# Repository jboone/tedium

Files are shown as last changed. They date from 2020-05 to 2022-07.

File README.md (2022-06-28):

# tedium

TDM telephony experimentation

## Dependencies

* `oss-cad-suite`: open-source digital design and verification tools, with [nightly binary builds](https://github.com/YosysHQ/oss-cad-suite-build).
* [`poetry`](https://python-poetry.org/): Python dependencies and packaging management tool.
* `g++-riscv64-linux-gnu`
* `rustup toolchain install stable -t riscv32i-unknown-none-elf`

## Installation

Clone this repository, and generally follow these steps:

```bash
$ cd tedium
# Grant access through `udev` to the FTDI JTAG interface on the Tedium board.
$ sudo ln -sf ./99-tedium.rules /etc/udev/rules.d/
$ sudo udevadm control --reload-rules && sudo udevadm trigger
#
$ pip3 install poetry --user
# Might need to log out and in to get ~/.local/bin in PATH.
# Or, `source ~/.profile`.
# Set up virtual environment, download and install dependencies
$ poetry install
# Enter poetry shell
$ poetry shell
# Include OSS CAD Suite tools in PATH
$ export PATH="/home/jboone/src/fpga/oss-cad-suite/bin:$PATH"
# Build and download FPGA bitstream
# LUNA_AVOID_BLOCKRAM required for reliable USB enumeration as of 2022/May/02.
$ LUNA_AVOID_BLOCKRAM=1 applets/tedium-fpga
# After the bitstream is generated, you can inspect the results in the `build` directory.
# Initialize the framer/LIU
$ cargo run --release --bin tedium-tool -- init
# Run the host-side audio and event engine
$ cargo run --release --bin tedium-tool -- monitor
```

NOTE: My Tedium .venv got weird when I had the "OSS CAD Suite" environment already enabled.
Poetry would download dependencies on `poetry install` or `poetry update`, but would then
delete them when running `poetry run` or `poetry shell`.

## Testing

Unit tests may be run like this:

```bash
$ python3 -m unittest tests.hdl.tx_usb_to_fifo
# Or the name of any other HDL test module you want to run/simulate.
```

## USB Debugging

```bash
$ sudo cat /sys/kernel/debug/usb/devices
$ sudo cat /sys/kernel/debug/dynamic_debug/control | grep "snd_usb_audio"
$ sudo echo 'file sound/usb/* +p' >/sys/kernel/debug/dynamic_debug/control
$ sudo sysctl -w kernel.printk=7 # debug-level messages
$ sudo sysctl kernel.printk
```

### Using Wireshark

```bash
$ sudo modprobe usbmon
$ sudo wireshark
# Capture stuff
```

Wireshark filters that might be of use:

```
# Find USB IN on endpoint 1, where the frame of completed inbound URBs is not the typical length.
# This helps find where the async audio input FIFO level is wrapping around.
usb.endpoint_address.number==1 && usb.endpoint_address.direction==IN && usb.urb_type=='C' && frame.len != 1728
# Set the time reference at an interesting record in Wireshark, disable view filtering, and work from there.
# Note that "marked" records appear regardless of whether they match the view filter, which is very handy.
# Now match on USB OUT records that have been submitted (pending transmission)
usb.endpoint_address.number==1 && usb.endpoint_address.direction==OUT && usb.urb_type=='S'
```

However, it seems like Wireshark isn't showing complete URB buffer contents?

## Trouble With Real-Time Kit

```bash
# Is there an `rtkit` user?
$ getent passwd rtkit
# Is there an `rtkit*` user?
$ ps ax | grep -i rtkit
# Check that RTKit is actually changing our process/thread priority:
$ journalctl -e -t rtkit-daemon
# `ulimit` values:
$ ulimit -a
```

## Use

See [the software README](tedium/README.md) for information on how to use `tedium-tool` to interact with the hardware over USB.

## License

This software and gateware in this project is licensed under the [BSD 3-Clause License](LICENSE-BSD-3-Clause).

The hardware is licensed under the [CERN Open Hardware Licence Version 2 - Permissive](LICENSE-CERN-OHL-P-v2).

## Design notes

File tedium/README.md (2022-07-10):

# Hardware Setup

The anticipated use case will be for Tedium to recover the clock on span 0 and distribute it to all spans (including span 0 TX).

* Tedium span 0: T-BERD 950 "Line" (primary system clock source)
* Tedium span 1: Adit 1 span 0 (primary source for Adit 1)
* Tedium span 2: Adit 1 span 1 (secondary source for Adit 1)

The T-BERD should be set up accordingly:

* Main
  * Interface: T1
  * Test Type: VOICE

* Setup
  * Mode: TERMINATE
  * Framing: ESF
  * Line Coding: B8ZS
  * Line Rx In: TERM
  * Tx/Rx Pair: LINE
  * Tx Timing: INTERNAL

Don't use the T-BERD "Equipment" DDS-LL port, as it's pretty certain it doesn't do what I'd expect and need it to do.

The Adit 600 should be set up accordingly:

"""
set a:1 up
set a:1 framing esf
set a:1 linecode b8zs
set a:1 lbo 1
set a:1 fdl t1403
set a:1 loopdetect csu
set a:1 payload loopdown
set a:1 ais disable

set a:1:all type voice
set a:1:all signal ls

# Transmit clocks, primary and secondary
# Use the first span RX as the TX source, then the second span RX.
set clock1 A:1
set clock2 A:2

# ???
show idle
show autoexit
set autoexit off
show local
set local off
log
show screen
set screen 75
set screen off
"""

Review the configuration:

"""
show a:1
show a:2

show connect a:all

show clock
status clock
"""

# Configuration

To run `tedium-tool`, you need the latest stable Rust language installation.

You'll also likely want to add a `udev` rule to allow non-superuser access to the Tedium USB interface. Depending on your distribution, you'll want to use the `debian` or `arch` udev rules.

```bash
# Ubuntu
$ sudo cp 99-tedium-ubuntu.rules /etc/udev/rules.d/
# Arch
$ sudo cp 99-tedium-arch.rules /etc/udev/rules.d/
```

Then reload the rules:

```bash
$ sudo udevadm control --reload-rules
$ sudo udevadm trigger
```

# Building and Downloading the Gateware

__TODO__: These are notes from my temporary setup. Fill this out when everything stabilizes a bit.

```bash
PYTHONPATH=../luna:../lambdasoc:../minerva:. LUNA_AVOID_BLOCKRAM=1 applets/tedium-fpga
```

To reload the gateware on the FPGA (because something crashed or it otherwise can't be negotiated with), this saves having to rebuild the whole bitstream:

```bash
$ openocd -f build/design/top-openocd.cfg -c 'init; svf -quiet build/design/top.svf; exit'
```

Uploading the firmware onto the SoC: See the `tedium-soc` directory README.md.

# Framer/LIU Testing

Upon loading the gateware into the FPGA, you'll need to reset the framer/LIU chip.

```bash
$ ./tedium-tool reset
```

Dump the current state of the framer/LIU chip's registers:

```bash
$ ./tedium-tool dump
```

Transmit unframed BERT w/Daly pattern:

```bash
$ ./tedium-tool write 0x0163 0b0000_1001
$ ./tedium-tool write 0x0121 0b0000_0001
$ ./tedium-tool write 0x0123 0b0000_0100
```

Also receive and check BERT pattern:

```bash
$ ./tedium-tool write 0x0163 0b0000_1001
$ ./tedium-tool write 0x0121 0b0000_0001
$ ./tedium-tool write 0x0123 0b0000_1100
```

I think I finally understand the D/E time slots mentioned in the T1 registers documentation. I think that allows you to configure any combination of RX/TX time slots as an LAPD "stream".

# USB Monitoring for Debug

Assuming Ubuntu Linux, employing [ktemkin's guide](https://usb.ktemkin.com/usbmon), or the [Linux kernel documentation for usbmon](https://www.kernel.org/doc/Documentation/usb/usbmon.txt):

```bash
$ sudo modprobe usbmon
$ lsusb -tv | grep "16d0:0f3b"
# Identify "Bus" <n> that target device (vid:pid:name) is on.
...
Bus 003 Device 045: ID 16d0:0f3b MCS Tedium X8
...
$ sudo cat /sys/kernel/debug/usb/devices
...
T:  Bus=03 Lev=01 Prnt=01 Port=02 Cnt=03 Dev#= 45 Spd=480  MxCh= 0
D:  Ver= 2.00 Cls=00(>ifc ) Sub=00 Prot=00 MxPS=64 #Cfgs=  1
P:  Vendor=16d0 ProdID=0f3b Rev= 1.01
S:  Manufacturer=ShareBrained
S:  Product=Tedium X8
C:* #Ifs= 3 Cfg#= 1 Atr=c0 MxPwr=100mA
I:* If#= 0 Alt= 0 #EPs= 1 Cls=ff(vend.) Sub=ff Prot=ff Driver=(none)
E:  Ad=89(I) Atr=03(Int.) MxPS=  64 Ivl=1ms
I:* If#= 1 Alt= 0 #EPs= 0 Cls=ff(vend.) Sub=ff Prot=ff Driver=(none)
I:  If#= 1 Alt= 1 #EPs= 1 Cls=ff(vend.) Sub=ff Prot=ff Driver=(none)
E:  Ad=01(O) Atr=05(Isoc) MxPS= 384 Ivl=125us
I:* If#= 2 Alt= 0 #EPs= 0 Cls=ff(vend.) Sub=ff Prot=ff Driver=(none)
I:  If#= 2 Alt= 1 #EPs= 1 Cls=ff(vend.) Sub=ff Prot=ff Driver=(none)
E:  Ad=82(I) Atr=05(Isoc) MxPS= 384 Ivl=125us
...
```

Launch Wireshark and choose the usbmon<n> to capture from. You may need to `sudo dpkg-reconfigure wireshark-common` and permit non-superusers to be able to capture packets, and add yourself to the `wireshark` group, then log out/in. Wireshark GUI will provide a reminder dialog about this if you try to open a usbmon interface without adequate permissions.

You might also need to add udev permissions for `plugdev` to the `usbmon` devices:

```bash
echo 'SUBSYSTEM=="usbmon", GROUP="plugdev", MODE="640"' | sudo tee /etc/udev/rules.d/50-accessible-usbmon.rules
sudo udevadm control --reload-rules
sudo udevadm trigger
```

# Running Tests

Tests can be run in root of tedium project or a subdirectory. Poetry will provide the correct module path info.

Specify `GENERATE_VCDS=1` if you want GTKwave project and waveform outputs from each test.

```bash
# Make a directory to put test output -- GTKwave project and waveform files.
mkdir tmp
cd tmp
GENERATE_VCDS=1 poetry run python -m unittest tedium.gateware.test.test_enumerate
# Or you can run LUNA tests.
GENERATE_VCDS=1 poetry run python -m unittest luna.gateware.usb.usb2.descriptor
```

# Running New Code on the Tedium SoC

Be careful using the `lambdasoc` BIOS. The memory read/write/copy instructions default to parsing addresses as decimal unless you prefix with `0x`. And if you attempt to access an invalid address, the SoC (or at least the BIOS) hangs.

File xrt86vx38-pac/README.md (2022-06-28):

# xrt86vx38-pac

This is a peripheral access crate for the Exar/Maxlinear XRT86VX38 T1/E1 framer integrated circuit.

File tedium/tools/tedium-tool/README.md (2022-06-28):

# tedium-tool

This thing needs its own readme.

`tedium-tool` interacts with the Tedium hardware over USB. It mainly pumps audio and events back and forth over USB, and tries (and presently fails miserably) at pretending to be a telephone switch.

## Running

```bash
$ cargo run --bin tedium-tool --release -- monitor
```

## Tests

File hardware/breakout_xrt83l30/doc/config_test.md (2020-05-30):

# Configuration for Initial Test

3.3V power applied at ICT# 3.3V and ground jumper pins.

MCLKT1 receives 1.544MHz @ 3.3V from a signal generator

Unspecified pins are not connected.

### J3

RESET# = 1
TERSEL[1:0] = 2b00
RXTSEL = 1
TXTSEL = 1
JABW = 0
JASEL[1:0] = 2b00
GAUGE = X
RXMUTE = 0
RXRES[1:0] = 2b00
RCLKE = 0
TXTEST[2:0] = 3b000
TCLKE = 0
TXON = 1

### J6

INSBPV = 0
NLCDE[1:0] = 2b00
LOOP[1:0] = 2b00 (RX channel audio passes, but connected Adit interface will not be "up") or 2b10 (remote loopback, however hook doesn't work, audio mostly isn't passed)
SD/DR# = 1

TRATIO = 1
EQC0/INT# = 0
EQC1/CS# = 0
EQC2/SCLK = 0
EQC3/SDO = 1
EQC4/SDI = 0
HW/HOST# = 1
CLKSEL[2:0] = 3b001

### J1

TNEG_CODES = 0 (pulled down, don't need to connect)

### J2

RCLK outputs recovered receive clock
RPOS_RDATA outputs received data after B8ZS decoding

# Configuration 2020/04/01 (No Joke!)

## Datasheet Notes

Jitter Attenuator: "NOTE: If the LIU is used in a loop timing system, the jitter attenuator should be enabled in the receive path."

T1 book recommends running in "loop" mode, using RX as source of timing, and repeating that on the TX side.
In multi-span architectures, one span RX would be chosen as the source of timing, and hopefully the other spans would be on the same clock already?
In a peering-to-ShadyTel situation, we'd have a span to them act as our clock source, and we'd use that for spans to Adits, etc.?

FPGA sends 8kHz clock to MCLKE1 input on LIU

RESET#		= 1			// Normal operation
TERSEL[1:0]	= 2'b00		// Internal termination impedance: 100 Ohms
RXTSEL		= 1			// RX termination: internal			
TXTSEL		= 1			// TX termination: internal
JABW		= 0			// Jitter attenuator bandwidth: in T1, this setting doesn't matter, bandwidth is always 3Hz.
JASEL[1:0]	= 2'b11		// Jitter attenuator selection: attenuate jitter on T1 receiver, 3dB, 64-bit FIFO depth.
GAUGE       = _
RXMUTE		= 0
RXRES[1:0]	= 2'b00		// Receive external resistor: No external fixed resistor
RCLKE		= 0
TXTEST[2:0]	= 3'b000
TCLKE		= 0
TXON		= 1

INSBPV		= 0			// Insert bipolar violation: disabled
NLCDE[1:0]	= 2'b00		// Network loop code detection: disabled
LOOP[1:0]   = 2'b00		// Loopback: Normal mode
SR/DR#      = 1         // Single-rail data format
TRATIO      = 1			// 1:2 transmitter transformer ratio. (Ignored if using internal termination mode.)
EQC[4:0]    = 5'b01000	// E1/T1 mode & Receive Sensitivity: T1 Short Haul / 15dB, Transmit LBO: 0-133 ft. / 0.6dB, Cable: 100 Ohm / TP, Coding: B8ZS
CLKSEL[2:0] = 3'b010	// 8kHz input to MCLKE1, clkout depends on MCLKRATE (set by EQC[4:0] in strapping pin mode)

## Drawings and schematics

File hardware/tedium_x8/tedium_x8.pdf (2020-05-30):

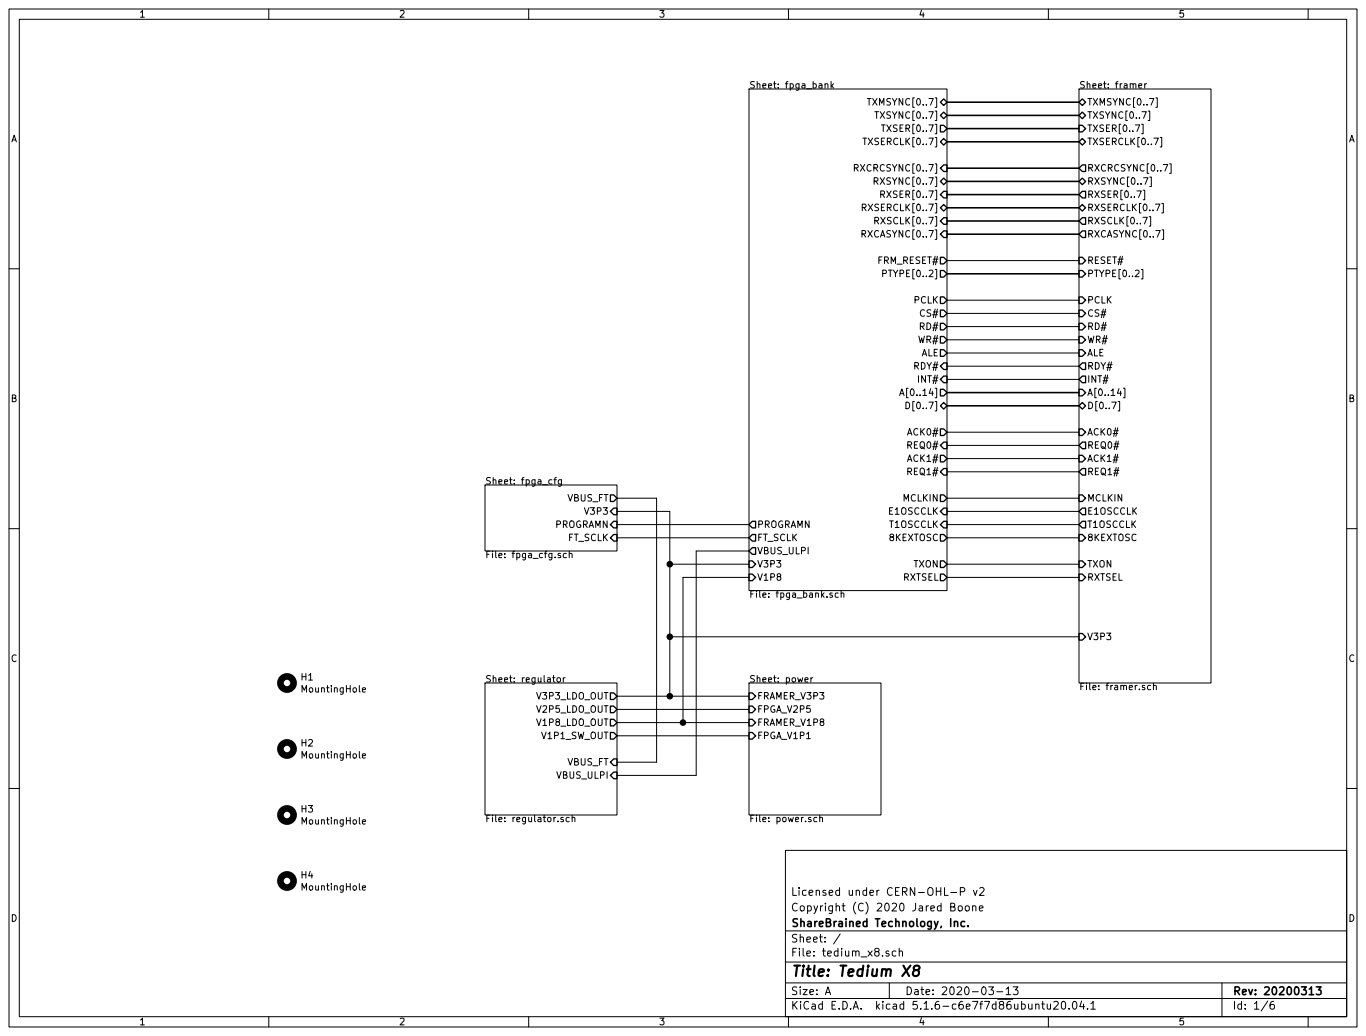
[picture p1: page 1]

TXMSYNC[0..7]
TXSYNC[0..7]
TXSER[0..7]
TXSERCLK[0..7]
RXCASYNC[0..7] MCLKIN
D[0..7] FRM_RESET# PTYPE[0..2] PCLK CS# RD# WR# ALE RDY#

Licensed under CERN-OHL-P v2 Sheet: fpga_cfg

Copyright (C) 2020 Jared Boone
File: tedium_x8.sch Sheet: / ShareBrained Technology, Inc.

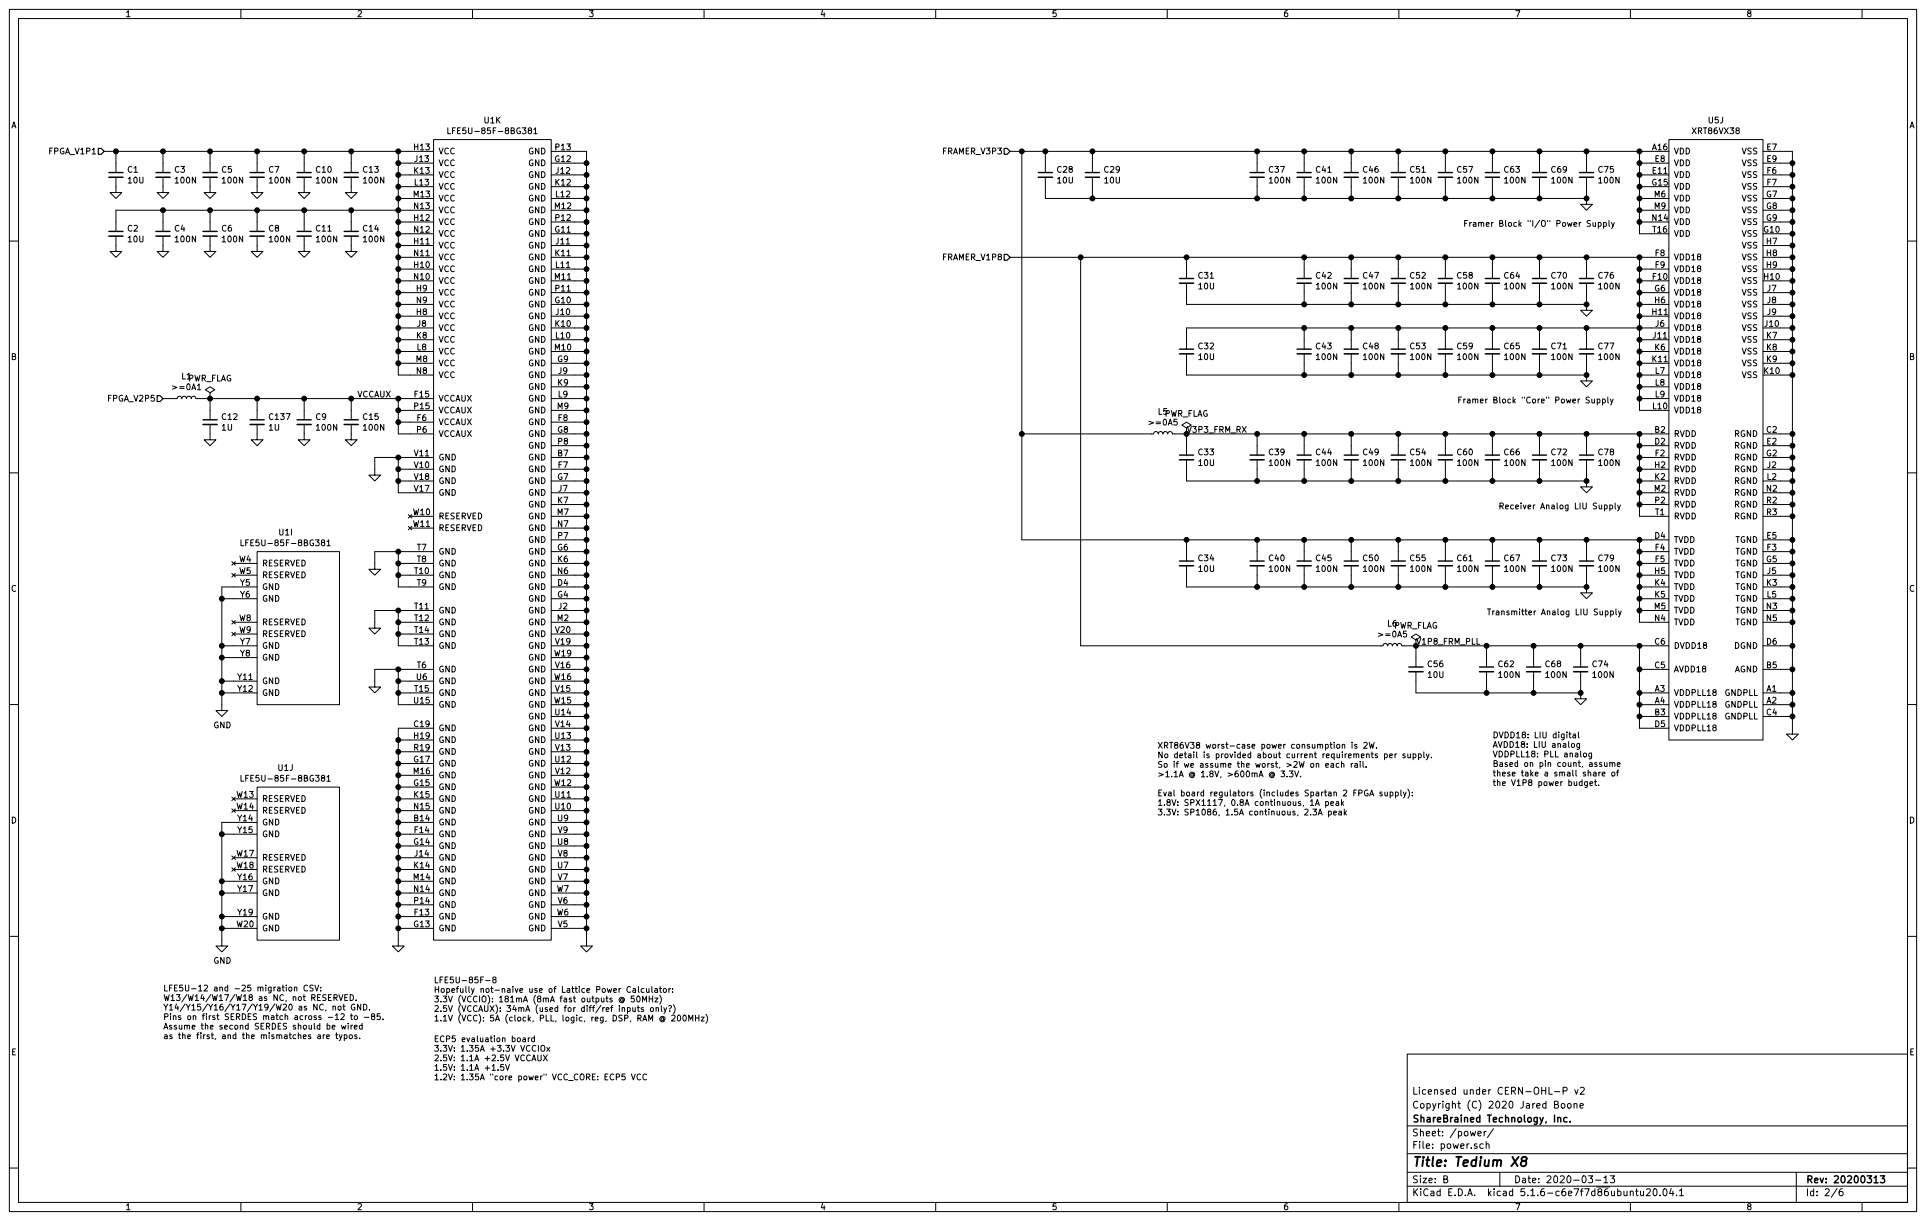
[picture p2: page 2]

Framer Block "I/O" Power Supply

Receiver Analog LIU Supply

Transmitter Analog LIU Supply

XRT86V38 worst-case power consumption is 2W.
No detail is provided about current requirements per supply. So if we assume the worst, >2W on each rail. >1.1A @ 1.8V, >600mA @ 3.3V.

DVDD18: LIU digital
AVDD18: LIU analog
VDDPLL18: PLL analog
Based on pin count, assume
these take a small share of
the V1P8 power budget.

Eval board regulators (includes Spartan 2 FPGA supply):
1.8V: SPX1117, 0.8A continuous, 1A peak

3.3V: SP1086, 1.5A continuous, 2.3A peak ECP5 evaluation board

LFE5U-85F-8 Hopefully not-naive use of Lattice Power Calculator:

LFE5U-12 and -25 migration CSV: W13/W14/W17/W18 as NC, not RESERVED. Y14/Y15/Y16/Y17/Y19/W20 as NC, not GND. Pins on first SERDES match across -12 to -85. Assume the second SERDES should be wired

3.3V (VCCIO): 181mA (8mA fast outputs @ 50MHz)
2.5V (VCCAUX): 34mA (used for diff/ref inputs only?)
1.1V (VCC): 5A (clock, PLL, logic, reg, DSP, RAM @ 200MHz)

as the first, and the mismatches are typos.

Licensed under CERN-OHL-P v2
Copyright (C) 2020 Jared Boone
ShareBrained Technology, Inc.
Sheet: /power/
File: power.sch
Id: 2/6 Title: Tedium X8

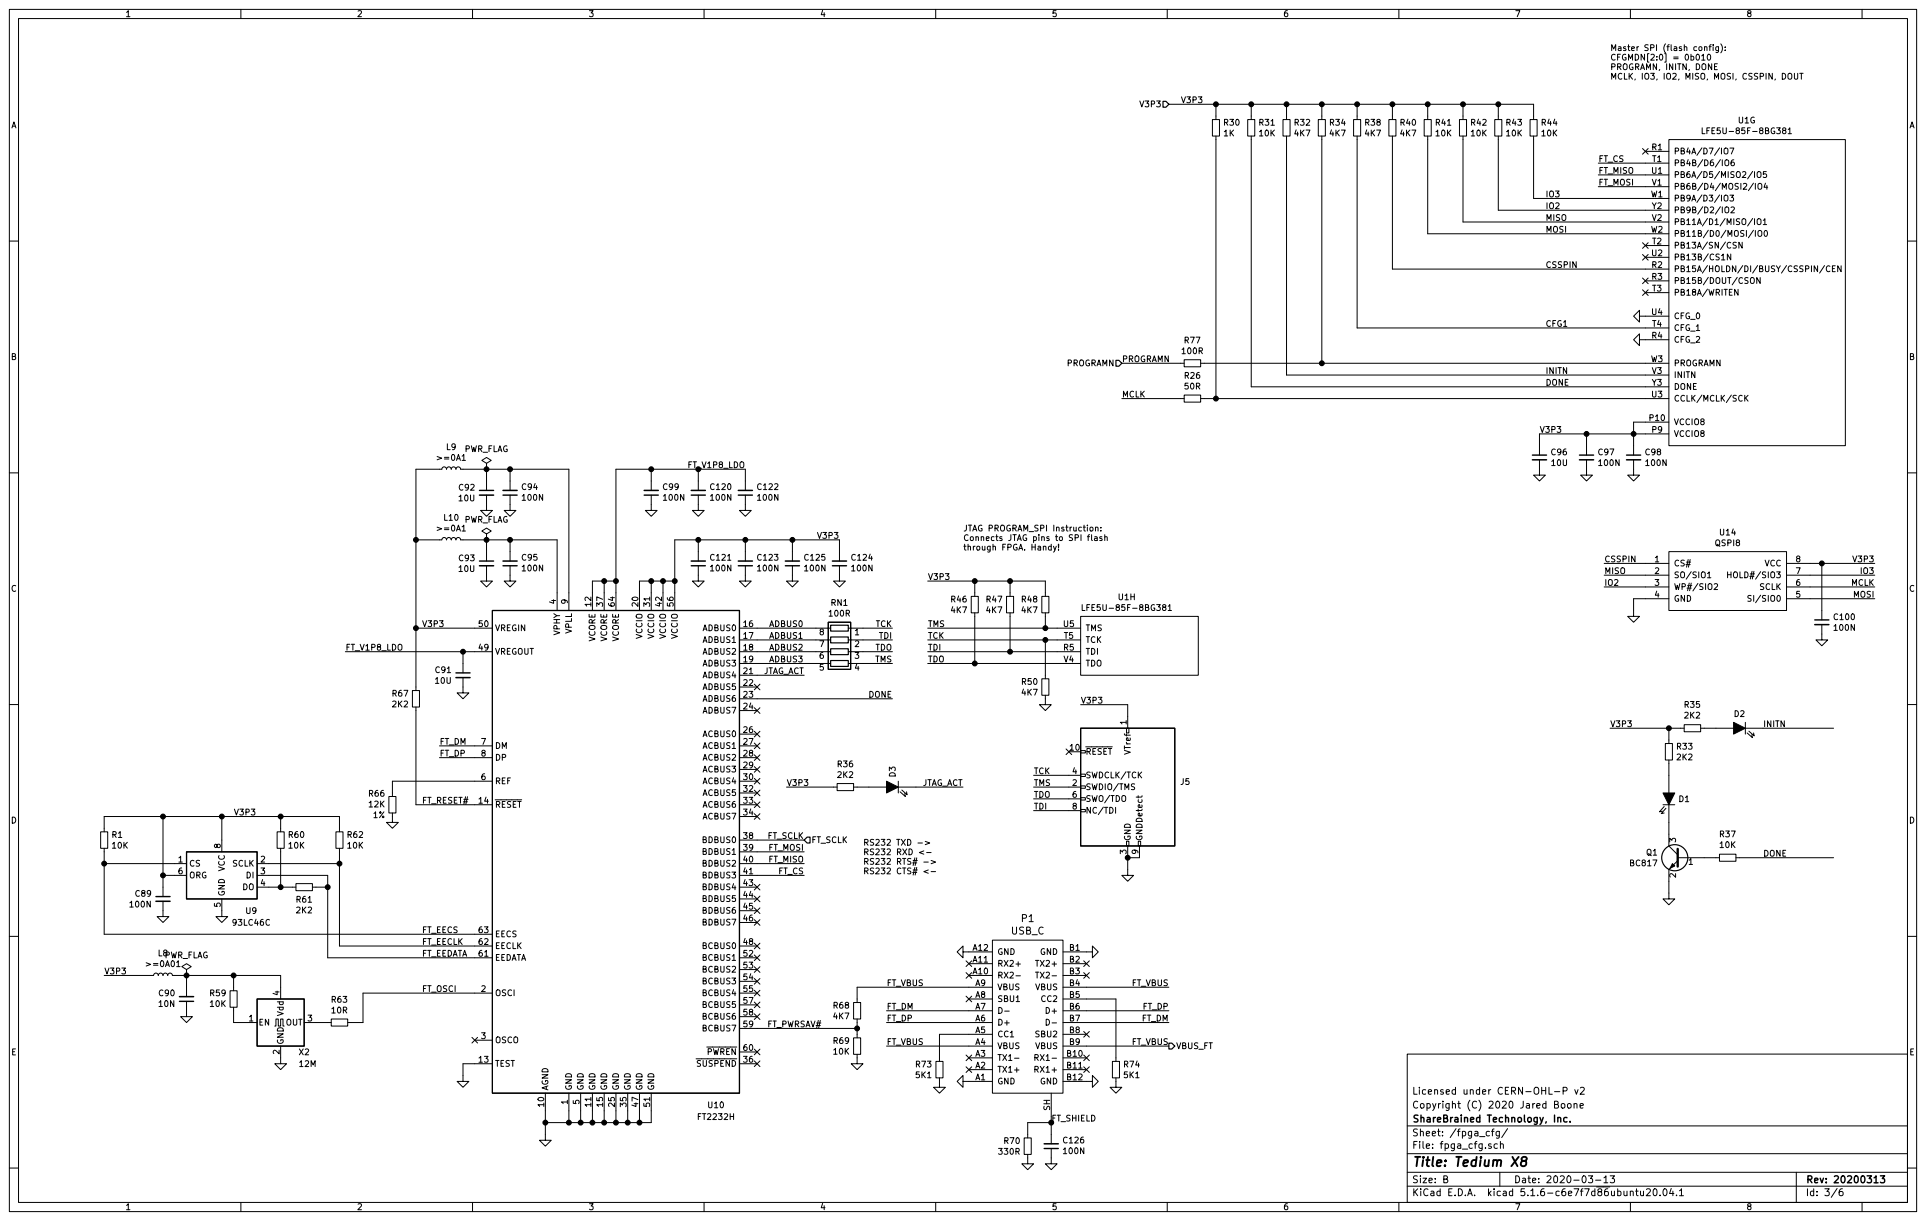
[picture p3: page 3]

Master SPI (flash config):
CFGMDN[2:0] = 0b010 PROGRAMN, INITN, DONE MCLK, IO3, IO2, MISO, MOSI, CSSPIN, DOUT

JTAG PROGRAM_SPI Instruction: Connects JTAG pins to SPI flash
TMS
TCK
TDI TDO

through FPGA. Handy! RS232 TXD -> RS232 RXD <- RS232 RTS# -> RS232 CTS# <-

1 AGND 10 GND 11 VCORE 12 TEST 13 RESET 14 GND 15 ADBUS0 16 ADBUS1 17 ADBUS2 18 ADBUS3 19 OSCI 2 VCCIO 20 ADBUS4 21 ADBUS5 22 ADBUS6 23 ADBUS7 24 GND 25 ACBUS0 26 ACBUS1 27 ACBUS2 28 ACBUS3 29 OSCO 3 ACBUS4 30 VCCIO 31 ACBUS5 32 ACBUS6 33 ACBUS7 34 GND 35 SUSPEND 36 VCORE 37 BDBUS0 38 BDBUS1 39 VPHY

4 BDBUS2 40 BDBUS3 41 VCCIO 42 BDBUS4 43 BDBUS5 44 BDBUS6 45 BDBUS7 46 GND 47 BCBUS0 48 VREGOUT 49 GND

5 VREGIN 50 GND 51 BCBUS1 52 BCBUS2 53 BCBUS3 54 BCBUS4 55 VCCIO 56 BCBUS5 57 BCBUS6 58 BCBUS7 59 REF 6 PWREN 60 EEDATA 61 EECLK 62 EECS 63 VCORE 64 DM 7 DP 8 VPLL

9 U10 FT2232H GND A1 RX2- A10 RX2+ A11 GND A12 TX1+ A2 TX1- A3 VBUS A4 CC1 A5 D+ A6 D- A7 SBU1 A8 VBUS A9 GND B1 RX1- B10 RX1+ B11 GND B12 TX2+ B2 TX2- B3 VBUS B4 CC2 B5 D+ B6 D- B7 SBU2 B8 VBUS B9 SH P1 USB_C D3 R46

3 SWDCLK/TCK 4 SWO/TDO 6 NC/TDI 8 GNDDetect 9

Licensed under CERN-OHL-P v2 R63

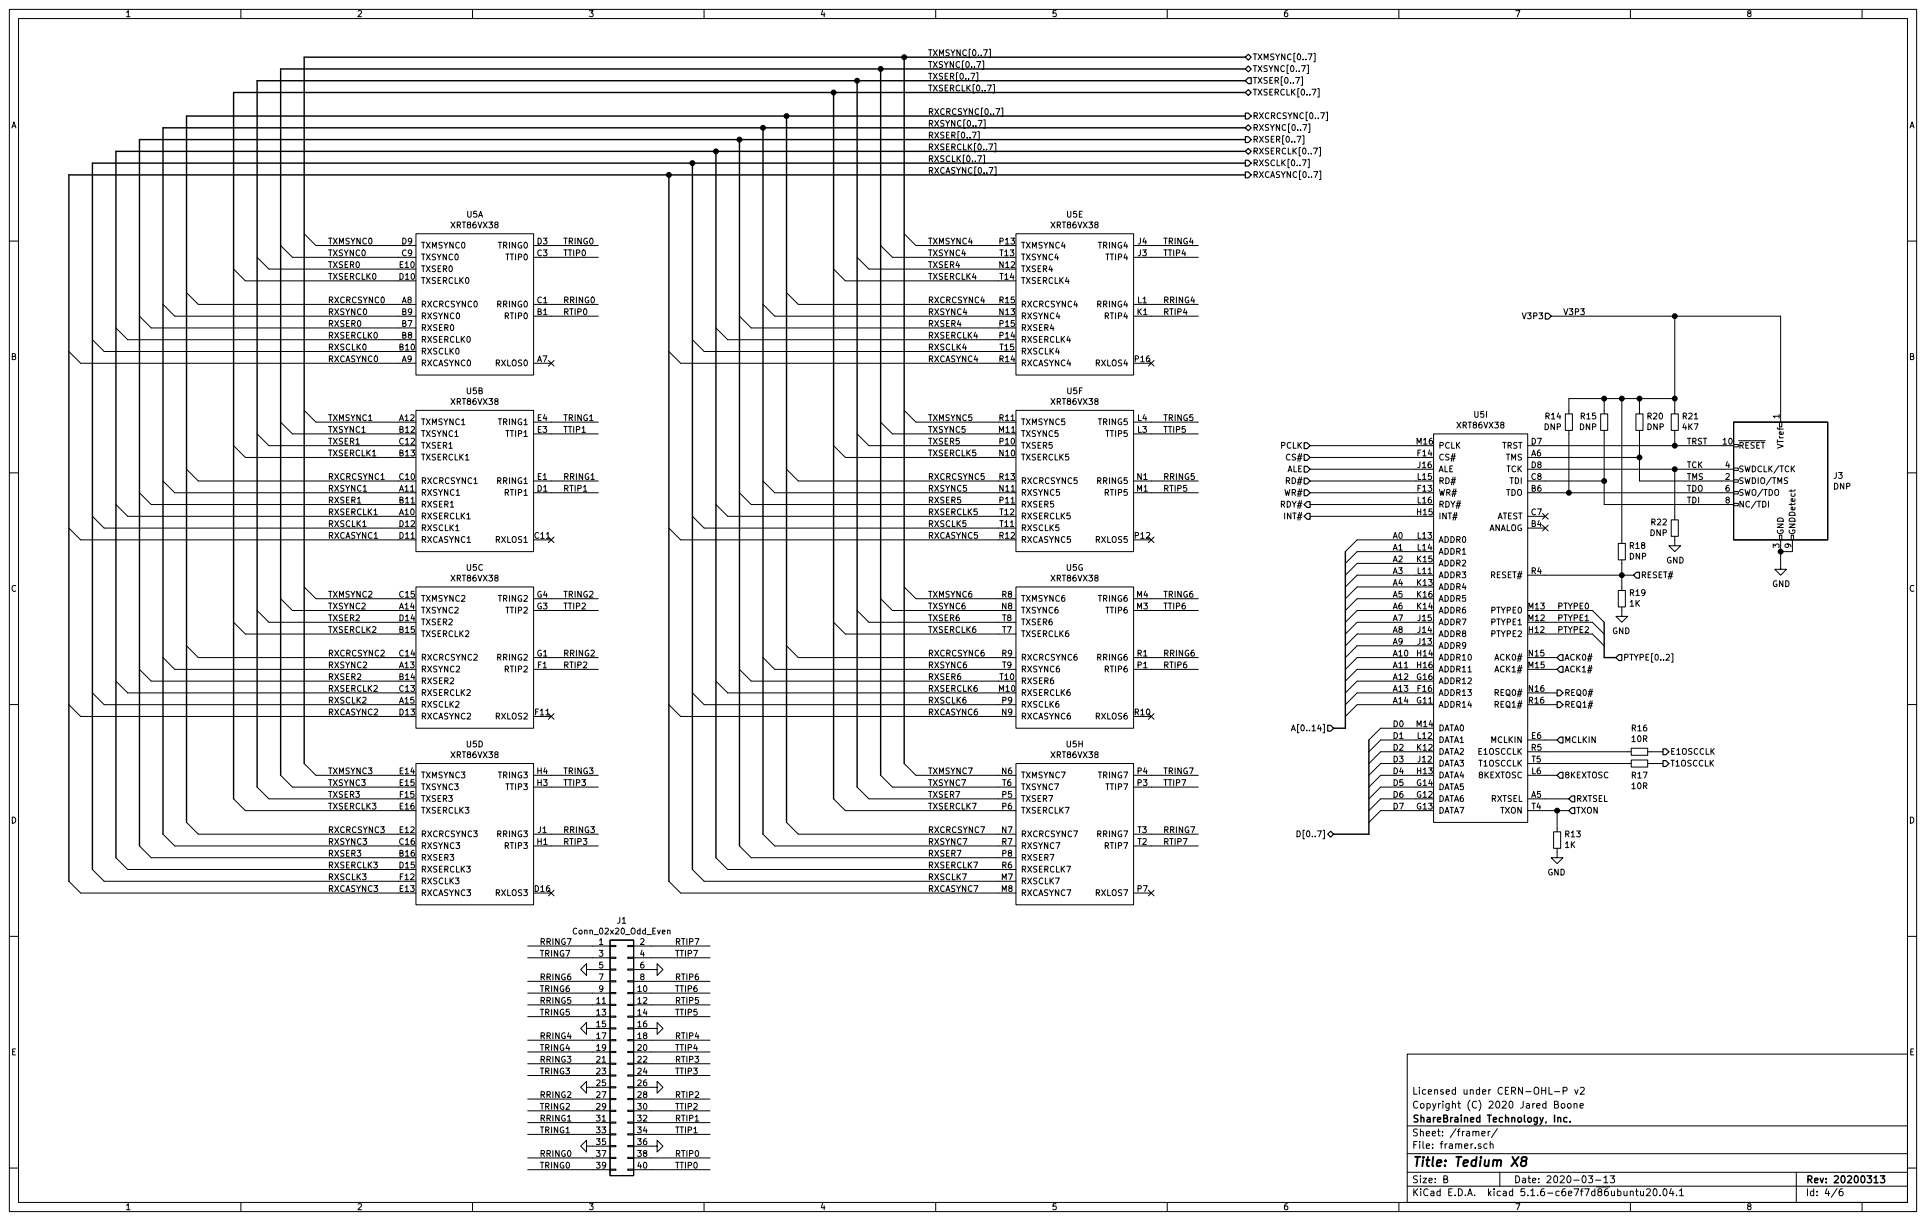
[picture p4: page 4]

Copyright (C) 2020 Jared Boone
File: framer.sch Sheet: /framer/ ShareBrained Technology, Inc.

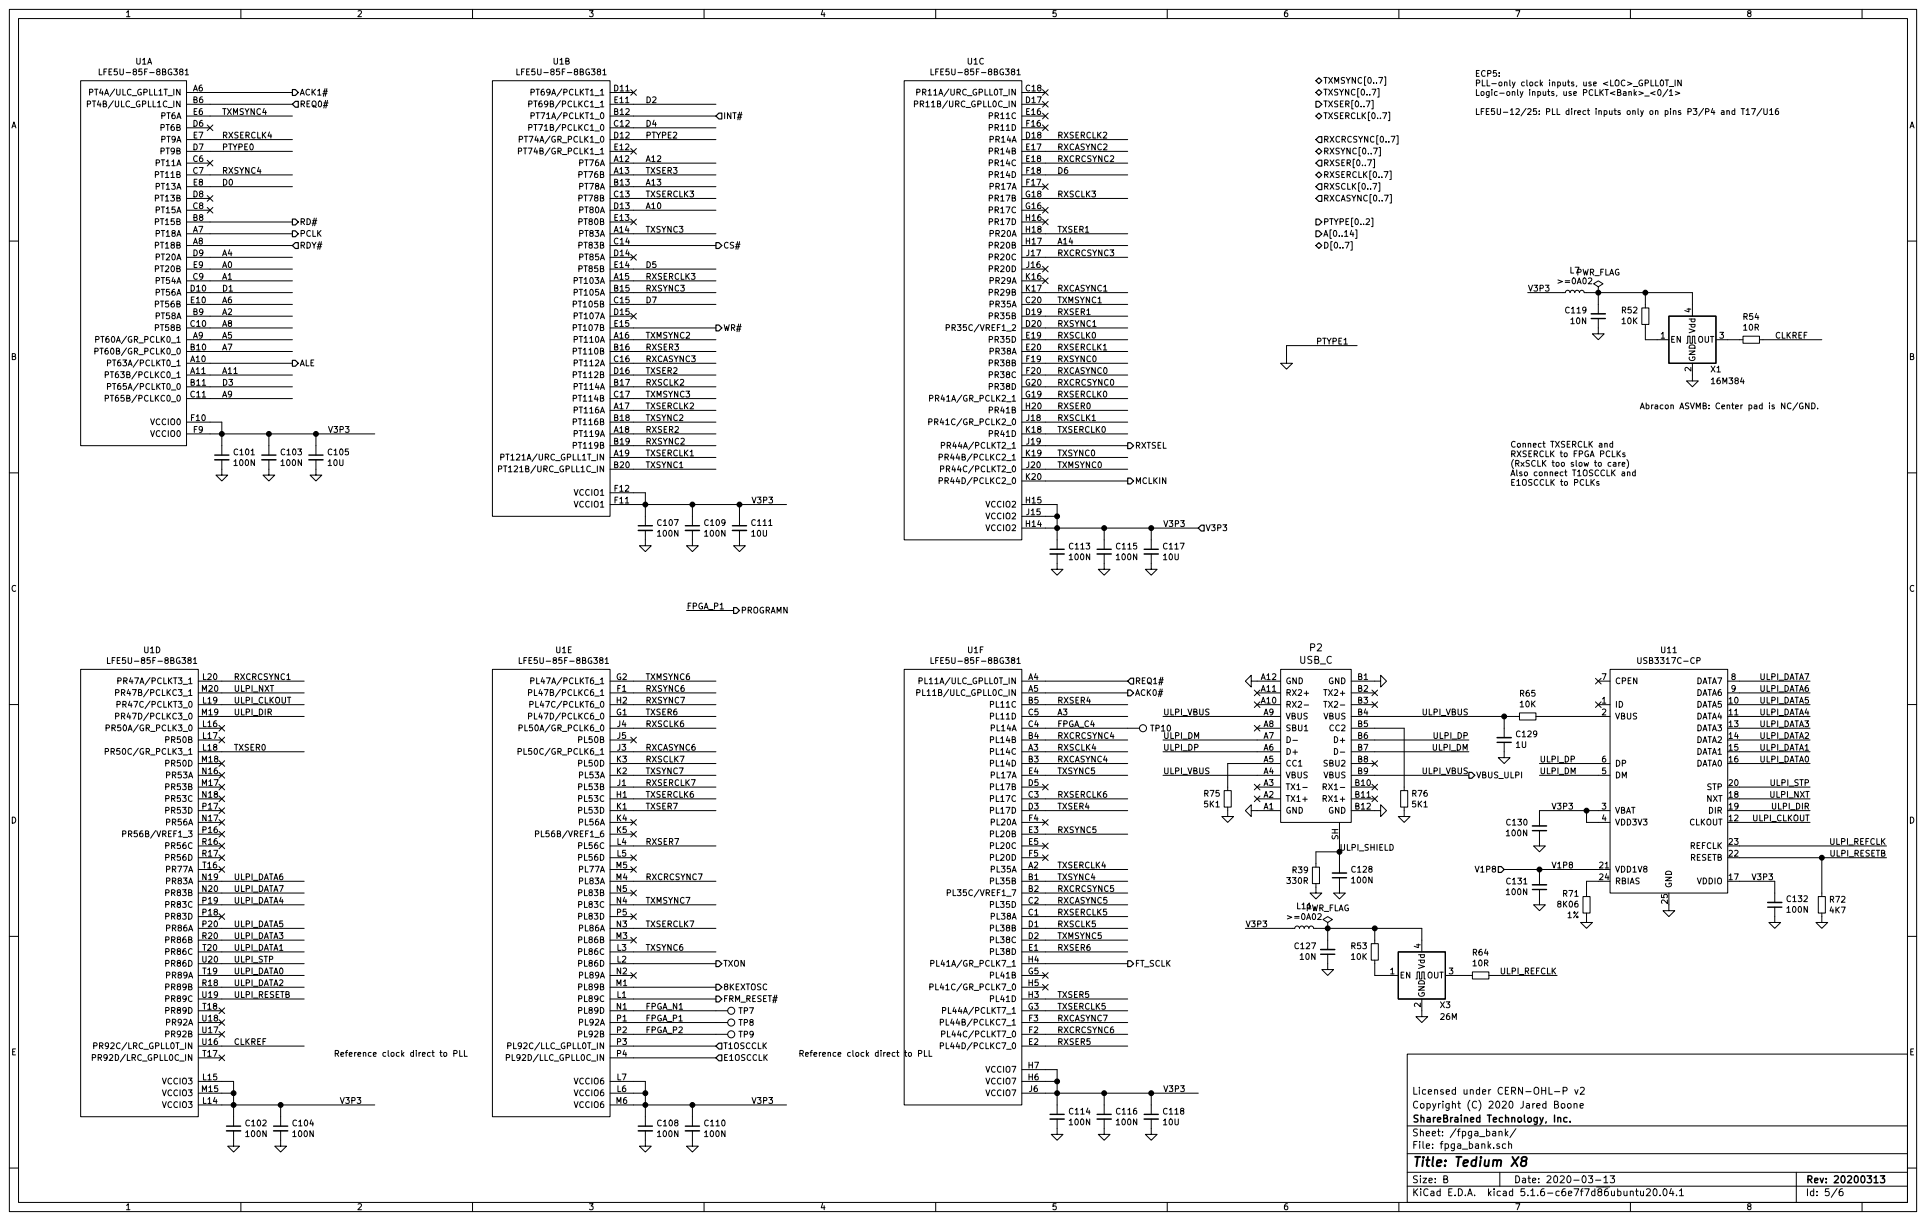
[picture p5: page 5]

ECP5: PLL-only clock inputs, use <LOC>_GPLL0T_IN

Logic-only inputs, use PCLKT<Bank>_<0/1>

LFE5U-12/25: PLL direct inputs only on pins P3/P4 and T17/U16

Abracon ASVMB: Center pad is NC/GND.

Connect TXSERCLK and RXSERCLK to FPGA PCLKs

(RxSCLK too slow to care) Also connect T1OSCCLK and E1OSCCLK to PCLKs

Licensed under CERN-OHL-P v2
Copyright (C) 2020 Jared Boone
ShareBrained Technology, Inc.
Sheet: /fpga_bank/
File: fpga_bank.sch
Id: 5/6 Title: Tedium X8

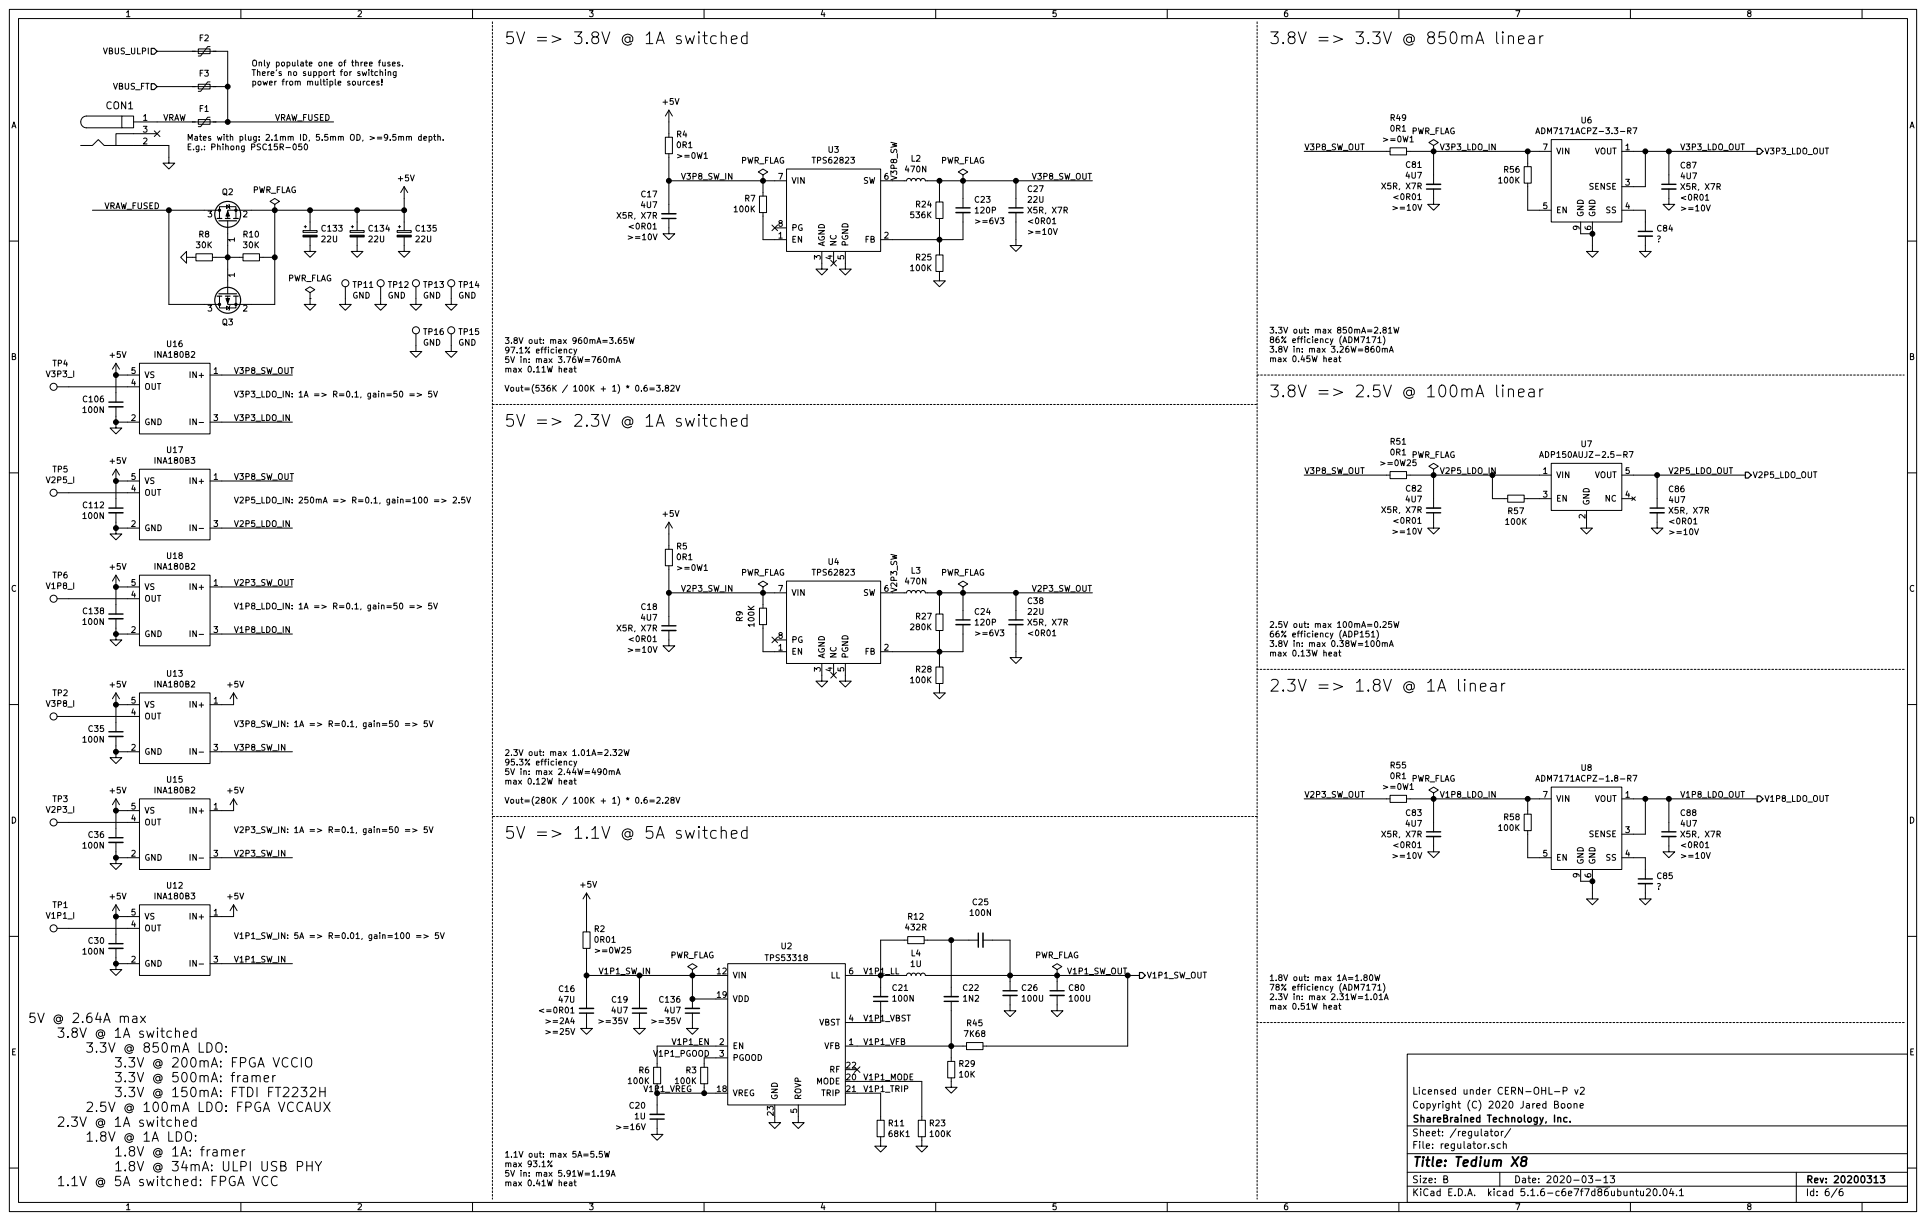
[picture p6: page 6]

Only populate one of three fuses.
There's no support for switching
power from multiple sources!

Mates with plug: 2.1mm ID, 5.5mm OD, >=9.5mm depth.
E.g.: Phihong PSC15R-050

3.3V out: max 850mA=2.81W
86% efficiency (ADM7171) 3.8V in: max 3.26W=860mA max 0.45W heat

3.8V out: max 960mA=3.65W
97.1% efficiency 5V in: max 3.76W=760mA max 0.11W heat Vout=(536K / 100K + 1) * 0.6=3.82V

2.5V out: max 100mA=0.25W
66% efficiency (ADP151) 3.8V in: max 0.38W=100mA max 0.13W heat

78% efficiency (ADM7171) 2.3V in: max 2.31W=1.01A max 0.51W heat 2.3V => 1.8V @ 1A linear

2.3V out: max 1.01A=2.32W
95.3% efficiency 5V in: max 2.44W=490mA max 0.12W heat Vout=(280K / 100K + 1) * 0.6=2.28V

Licensed under CERN-OHL-P v2
Copyright (C) 2020 Jared Boone
ShareBrained Technology, Inc.
Sheet: /regulator/
File: regulator.sch
Id: 6/6 Title: Tedium X8

1.1V out: max 5A=5.5W
max 93.1%
5V in: max 5.91W=1.19A max 0.41W heat

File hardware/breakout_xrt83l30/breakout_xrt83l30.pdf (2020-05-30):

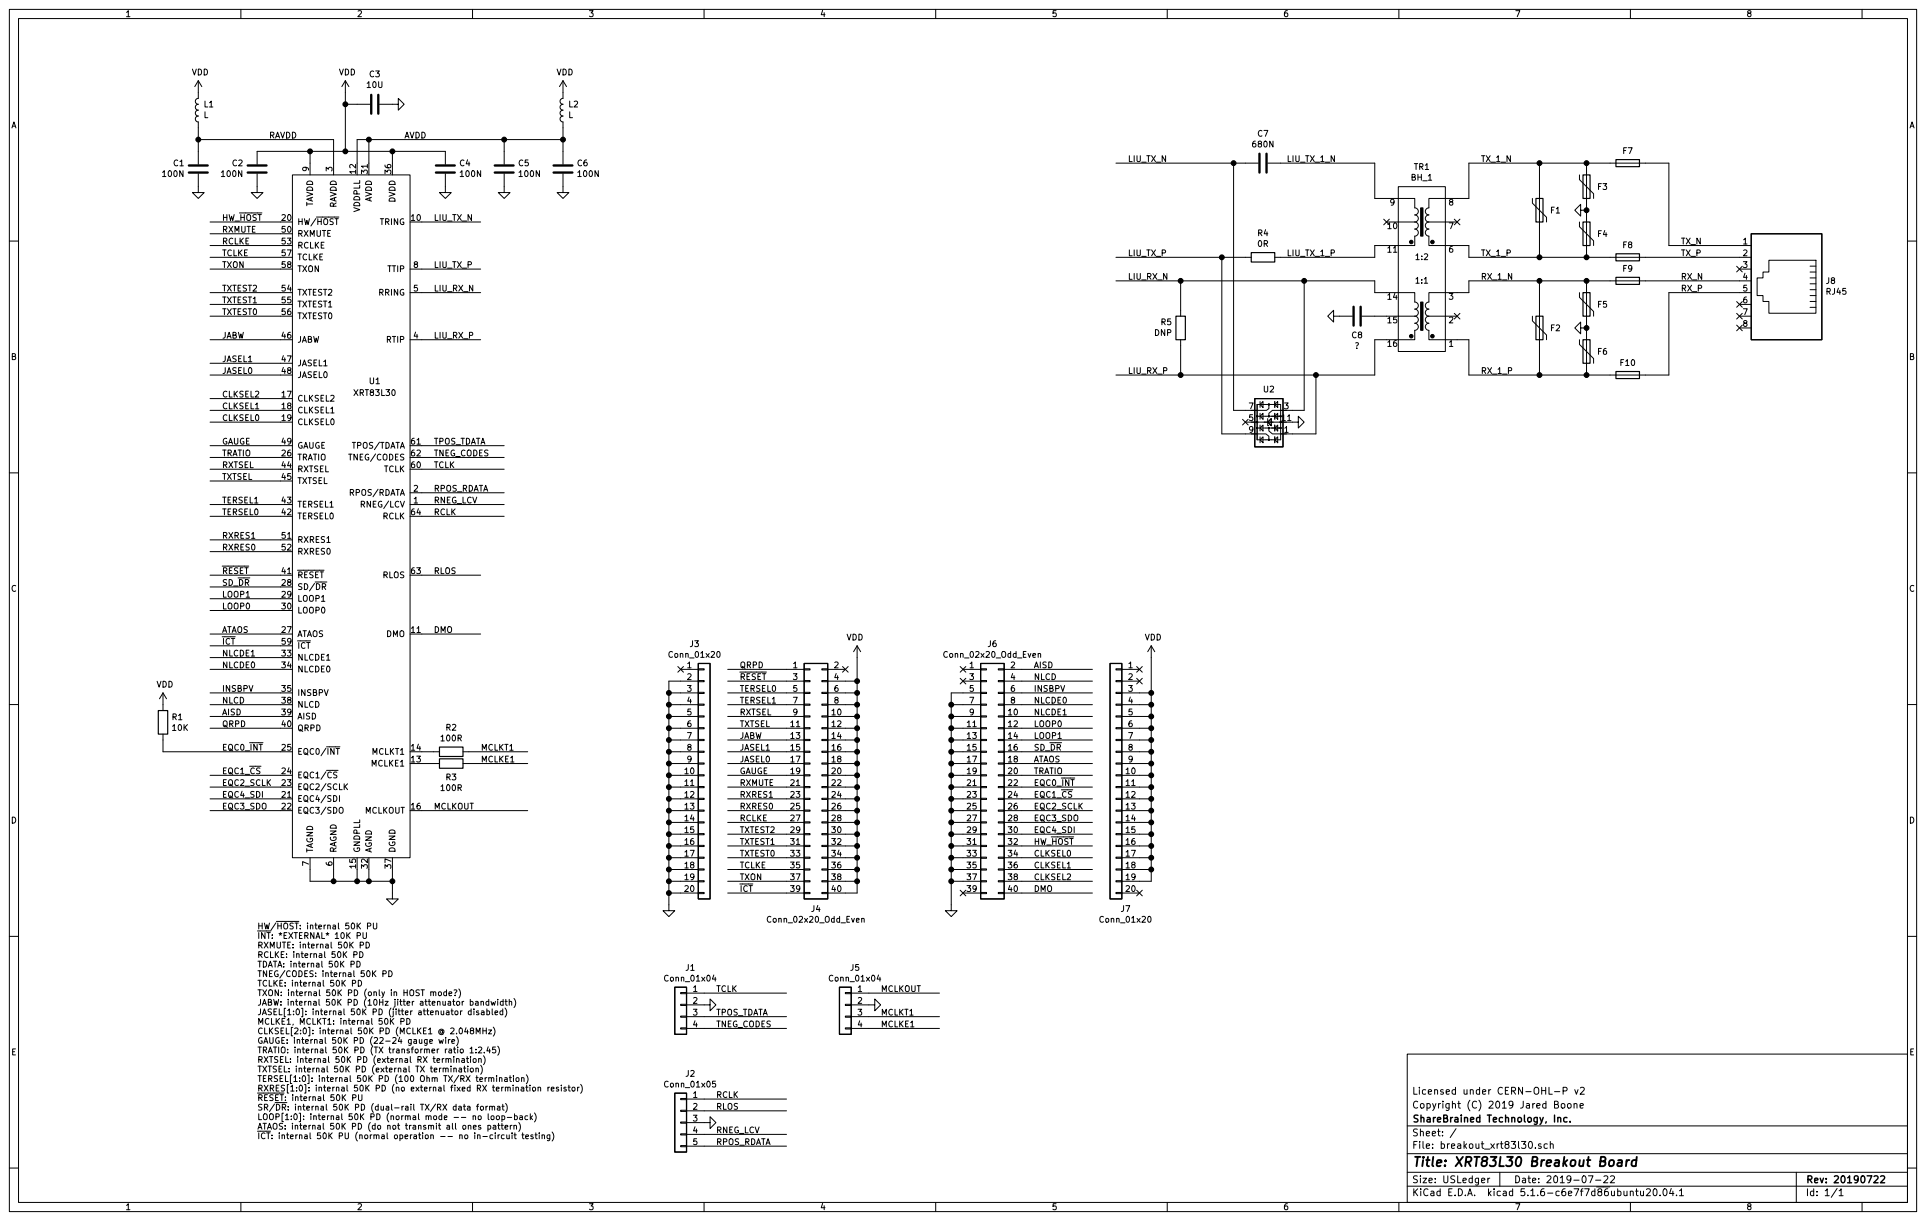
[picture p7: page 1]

INT: *EXTERNAL* 10K PU
RXMUTE: internal 50K PD
RCLKE: internal 50K PD
TDATA: internal 50K PD
TNEG/CODES: internal 50K PD
TCLKE: internal 50K PD
TXON: internal 50K PD (only in HOST mode?)
JABW: internal 50K PD (10Hz jitter attenuator bandwidth)
JASEL[1:0]: internal 50K PD (jitter attenuator disabled) MCLKE1, MCLKT1: internal 50K PD

CLKSEL[2:0]: internal 50K PD (MCLKE1 @ 2.048MHz)
GAUGE: internal 50K PD (22-24 gauge wire)
TRATIO: internal 50K PD (TX transformer ratio 1:2.45)
RXTSEL: internal 50K PD (external RX termination)
TXTSEL: internal 50K PD (external TX termination)
TERSEL[1:0]: internal 50K PD (100 Ohm TX/RX termination)
RXRES[1:0]: internal 50K PD (no external fixed RX termination resistor) RESET: internal 50K PU

Licensed under CERN-OHL-P v2
Copyright (C) 2019 Jared Boone
File: breakout_xrt83l30.sch Sheet: / ShareBrained Technology, Inc.

SR/DR: internal 50K PD (dual-rail TX/RX data format)
LOOP[1:0]: internal 50K PD (normal mode -- no loop-back)
ATAOS: internal 50K PD (do not transmit all ones pattern)
ICT: internal 50K PU (normal operation -- no in-circuit testing)

Id: 1/1 Title: XRT83L30 Breakout Board

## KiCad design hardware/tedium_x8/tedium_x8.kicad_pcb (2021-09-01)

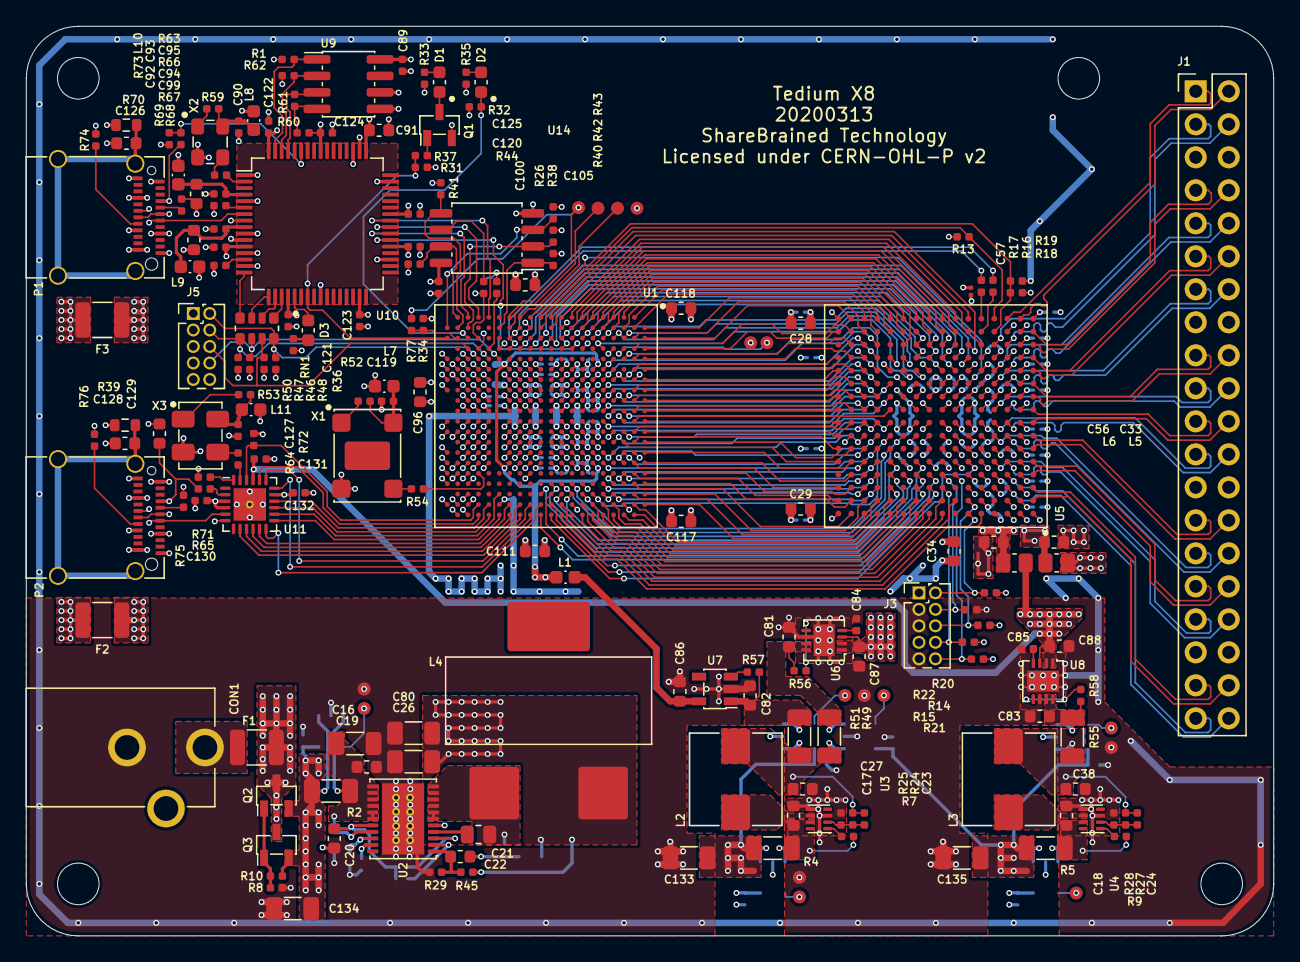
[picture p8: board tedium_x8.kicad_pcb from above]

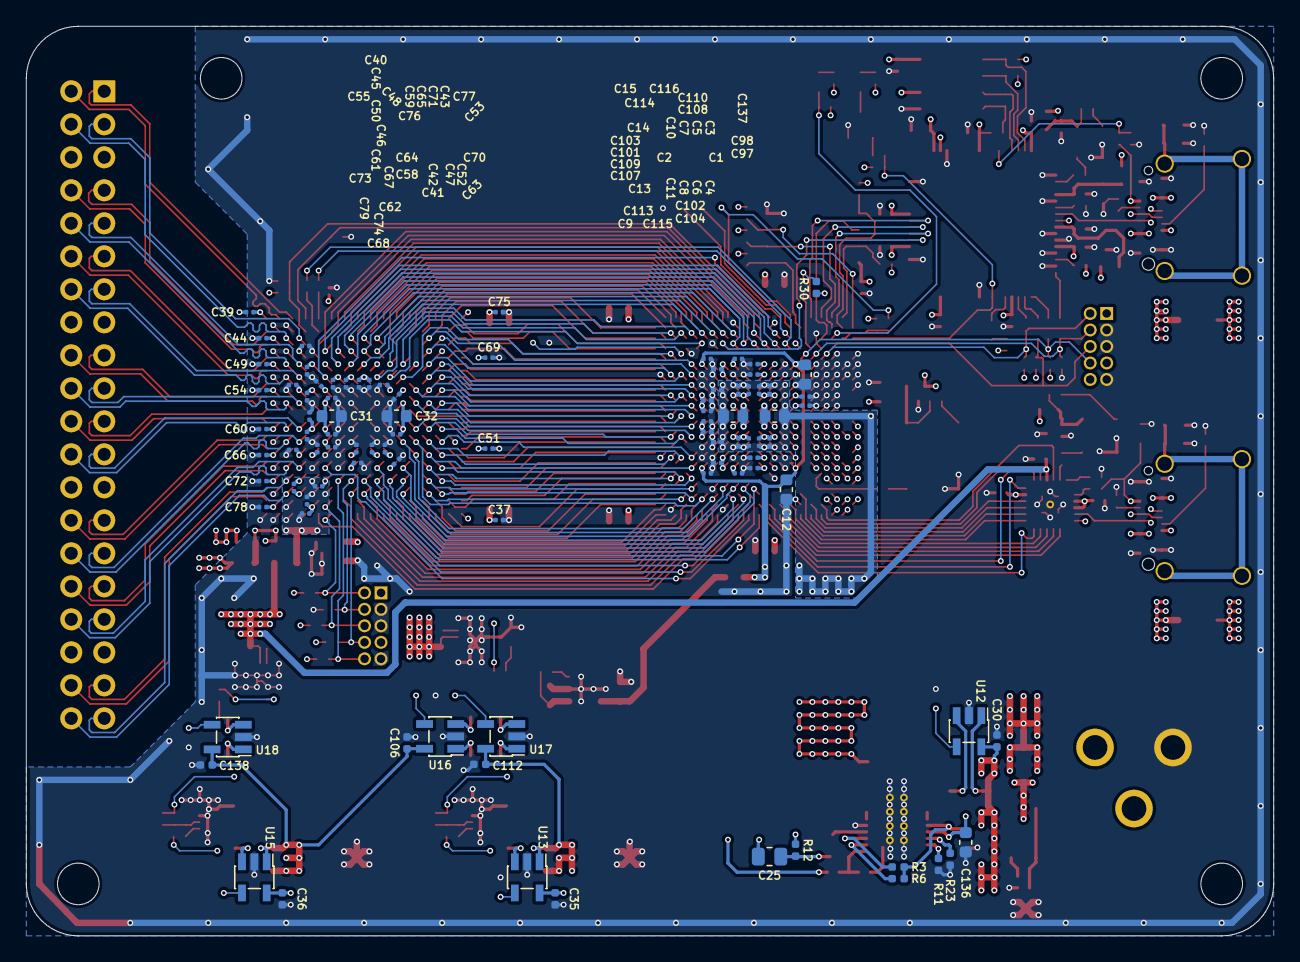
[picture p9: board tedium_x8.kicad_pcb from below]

Board: 4 copper layers, 96.0 x 70.0 mm, 283 parts (92 on the bottom side), 290 nets.

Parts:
C1, C2, C28, C29, C31, C32, C33, C34, C56, C91, C92, C93, C96, C105, C111, C117, C118: 10U; IPC_CAPC160X80X90L35N
C3, C4, C5, C6, C7, C8, C9, C10, C11, C13, C14, C15, C37, C39, C40, C41, C42, C43, C44, C45, C46, C47, C48, C49, C50, C51, C52, C53, C54, C55, C57, C58, C59, C60, C61, C62, C63, C64, C65, C66, C67, C68, C69, C70, C71, C72, C73, C74, C75, C76, C77, C78, C79, C97, C98, C101, C102, C103, C104, C107, C108, C109, C110, C113, C114, C115, C116: 100N; IPC_CAPC60X30X33L15N
C12, C20, C129, C137: 1U; IPC_CAPC160X80X90L35N
C16: 47U; IPC_CAPC320X160X180L55N
C17, C18, C19, C81, C82, C83, C86, C87, C88, C136: 4U7; IPC_CAPC160X80X90L35N
C21, C25: 100N; IPC_CAPC200X125X135L45N
C22: 1N2; IPC_CAPC160X80X90L35N
C23, C24: 120P; IPC_CAPC100X50X55L25N
C26, C80: 100U; IPC_CAPC320X160X180L55N
C27, C38: 22U; IPC_CAPC160X80X90L35N
C30, C35, C36, C89, C94, C95, C99, C100, C106, C112, C120, C121, C122, C123, C124, C125, C130, C131, C132, C138: 100N; IPC_CAPC100X50X55L25N
C84, C85: ?; IPC_CAPC100X50X55L25N
C90, C119, C127: 10N; IPC_CAPC100X50X55L25N
C126, C128: 100N; IPC_CAPC160X80X90L35N
C133, C134, C135: 22U; IPC_CAPC320X160X180L55N
CON1: BARREL_JACK; PJ-102AH
D1, D2, D3: LED; IPC_LEDC1608X90L40N
F1, F2, F3: Polyfuse_Small; IPC_FUSSC257X321X120L50N
H1, H2, H3, H4: MountingHole; MountingHole_3.2mm_M3
J1: Conn_02x20_Odd_Even; PinHeader_2x20_P2.54mm_Vertical
J3: DNP; PinHeader_2x05_P1.27mm_Vertical
J5: Conn_ARM_JTAG_SWD_10; PinHeader_2x05_P1.27mm_Vertical
L1, L7, L8, L9, L10, L11: L_Small; IPC_BEADC160X80X95L40N
L2, L3: 470N; WE-HCI_7050
L4: 1U; SER1590
L5, L6: L_Small; IPC_BEADC200X125X105L50N
P1, P2: USB_C; 12401610E4#2A
Q1: BC817; IPC_SOT23-3P95_237X112L50X42N
Q2, Q3: Q_PMOS_GSD; IPC_SOT23-3P95_237X112L50X42N
R1, R29, R31, R37, R41, R42, R43, R44, R52, R53, R59, R60, R62, R65, R69: 10K; IPC_RESC100X50X40L25N
R2: 0R01; IPC_RESC320X160X89L51N
R3, R6, R7, R9, R23, R25, R28, R56, R57, R58: 100K; IPC_RESC100X50X40L25N
R4, R5, R49, R51, R55: 0R1; IPC_RESC320X160X89L51N
R8, R10: 30K; IPC_RESC100X50X40L25N
R11: 68K1; IPC_RESC100X50X40L25N
R12: 432R; IPC_RESC100X50X40L25N
R13, R19, R30: 1K; IPC_RESC100X50X40L25N
R14, R15, R18, R20, R22: DNP; IPC_RESC100X50X40L25N
R16, R17, R54, R63, R64: 10R; IPC_RESC100X50X40L25N
R21, R32, R34, R38, R40, R46, R47, R48, R50, R68, R72: 4K7; IPC_RESC100X50X40L25N
R24: 536K; IPC_RESC100X50X40L25N
R26: 50R; IPC_RESC100X50X40L25N
R27: 280K; IPC_RESC100X50X40L25N
R33, R35, R36, R61, R67: 2K2; IPC_RESC100X50X40L25N
R39, R70: 330R; IPC_RESC160X80X55L25N
R45: 7K68; IPC_RESC100X50X40L25N
R66: 12K; IPC_RESC100X50X40L25N
R71: 8K06; IPC_RESC100X50X40L25N
R73, R74, R75, R76: 5K1; IPC_RESC100X50X40L25N
R77: 100R; IPC_RESC100X50X40L25N
RN1: 100R; IPC_RESCAXS8P80_320X160X60L30X45N
TP1: V1P1_I; TP_1MM
TP2: V3P8_I; TP_1MM
TP3: V2P3_I; TP_1MM
TP4: V3P3_I; TP_1MM
TP5: V2P5_I; TP_1MM
TP6: V1P8_I; TP_1MM
TP7, TP8, TP9, TP10: TestPoint; TP_1MM
TP11, TP12, TP13, TP14, TP15, TP16: GND; TP_1MM
U1: LFE5U-85F-8BG381; LATTICE_BGA_CABGA381
U2: TPS53318; IPC_SON23P50_600X500X150L50X27T547X324N
U3, U4: TPS62823; IPC_SON8P50_200X150X100L35X25N
U5: XRT86VX38; IPC_BGA256CP100_16X16_1700X1700X178B55N
U6: ADM7171ACPZ-3.3-R7; IPC_SON9P50_300X300X80L40X25T244X160N
U7: ADP150AUJZ-2.5-R7; IPC_SOT23-5P95_280X100L45X40N
U8: ADM7171ACPZ-1.8-R7; IPC_SON9P50_300X300X80L40X25T244X160N
U9: 93LC46C; IPC_SOIC8P127_490X600X175L83X41N
U10: FT2232H; IPC_QFP64P50_1200X1200X160L60X22N
U11: USB3317C-CP; IPC_QFN25P50_400X400X100L40X24T250N
U12, U17: INA180B3; TI_DBV_SOT-23-5
U13, U15, U16, U18: INA180B2; TI_DBV_SOT-23-5
U14: QSPI8; IPC_SOIC8P127_528X790X216L65X41N
X1: 16M384; ASVMB
X2: 12M; IPC_OSCCC320X250X120L75X100N
X3: 26M; IPC_OSCSC4P254_500X320X140L100X120N

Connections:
+5V: C30.1, C35.1, C36.1, C106.1, C112.1, C133.1, C134.1, C135.1, C138.1, Q2.2, Q3.2, R2.2, R4.2, R5.2, R10.2, U12.1, U12.5, U13.1, U13.5, U15.1, U15.5, U16.5, U17.5, U18.5
/fpga_bank/8KEXTOSC: U1.M1, U5.L6
/fpga_bank/A0: U1.E9, U5.L13
/fpga_bank/A1: U1.C9, U5.L14
/fpga_bank/A2: U1.B9, U5.K15
/fpga_bank/A3: U1.C5, U5.L11
/fpga_bank/A4: U1.D9, U5.K13
/fpga_bank/A5: U1.A9, U5.K16
/fpga_bank/A6: U1.E10, U5.K14
/fpga_bank/A7: U1.B10, U5.J15
/fpga_bank/A8: U1.C10, U5.J14
/fpga_bank/A9: U1.C11, U5.J13
/fpga_bank/A10: U1.D13, U5.H14
/fpga_bank/A11: U1.A11, U5.H16
/fpga_bank/A12: U1.A12, U5.G16
/fpga_bank/A13: U1.B13, U5.F16
/fpga_bank/A14: U1.H17, U5.G11
/fpga_bank/ACK0#: U1.A5, U5.N15
/fpga_bank/ACK1#: U1.A6, U5.M15
/fpga_bank/ALE: U1.A10, U5.J16
/fpga_bank/CLKREF: R54.2, U1.U16
/fpga_bank/CS#: U1.C14, U5.F14
/fpga_bank/D0: U1.E8, U5.M14
/fpga_bank/D1: U1.D10, U5.L12
/fpga_bank/D2: U1.E11, U5.K12
/fpga_bank/D3: U1.B11, U5.J12
/fpga_bank/D4: U1.C12, U5.H13
/fpga_bank/D5: U1.E14, U5.G14
/fpga_bank/D6: U1.F18, U5.G12
/fpga_bank/D7: U1.C15, U5.G13
/fpga_bank/E1OSCCLK: R16.1, U1.P4
/fpga_bank/FPGA_C4: TP10.1, U1.C4
/fpga_bank/FPGA_N1: TP7.1, U1.N1
/fpga_bank/FPGA_P2: TP9.1, U1.P2
/fpga_bank/FRM_RESET#: R18.1, R19.2, U1.L1, U5.R4
/fpga_bank/FT_SCLK: U1.H4, U10.38
/fpga_bank/INT#: U1.B12, U5.H15
/fpga_bank/MCLKIN: U1.K20, U5.E6
/fpga_bank/PCLK: U1.A7, U5.M16
/fpga_bank/PROGRAMN: R77.1, TP8.1, U1.P1
/fpga_bank/PTYPE0: U1.D7, U5.M13
/fpga_bank/PTYPE2: U1.D12, U5.H12
/fpga_bank/RD#: U1.B8, U5.L15
/fpga_bank/RDY#: U1.A8, U5.L16
/fpga_bank/REQ0#: U1.B6, U5.N16
/fpga_bank/REQ1#: U1.A4, U5.R16
/fpga_bank/RXCASYNC0: U1.F20, U5.A9
/fpga_bank/RXCASYNC1: U1.K17, U5.D11
/fpga_bank/RXCASYNC2: U1.E17, U5.D13
/fpga_bank/RXCASYNC3: U1.C16, U5.E13
/fpga_bank/RXCASYNC4: U1.B3, U5.R14
/fpga_bank/RXCASYNC5: U1.C2, U5.R12
/fpga_bank/RXCASYNC6: U1.J3, U5.N9
/fpga_bank/RXCASYNC7: U1.F3, U5.M8
/fpga_bank/RXCRCSYNC0: U1.G20, U5.A8
/fpga_bank/RXCRCSYNC1: U1.L20, U5.C10
/fpga_bank/RXCRCSYNC2: U1.E18, U5.C14
/fpga_bank/RXCRCSYNC3: U1.J17, U5.E12
/fpga_bank/RXCRCSYNC4: U1.B4, U5.R15
/fpga_bank/RXCRCSYNC5: U1.B2, U5.R13
/fpga_bank/RXCRCSYNC6: U1.F2, U5.R9
/fpga_bank/RXCRCSYNC7: U1.M4, U5.N7
/fpga_bank/RXSCLK0: U1.E19, U5.B10
/fpga_bank/RXSCLK1: U1.J18, U5.D12
/fpga_bank/RXSCLK2: U1.B17, U5.A15
/fpga_bank/RXSCLK3: U1.G18, U5.F12
/fpga_bank/RXSCLK4: U1.A3, U5.T15
/fpga_bank/RXSCLK5: U1.D1, U5.T11
/fpga_bank/RXSCLK6: U1.J4, U5.P9
/fpga_bank/RXSCLK7: U1.K3, U5.M7
/fpga_bank/RXSER0: U1.H20, U5.B7
/fpga_bank/RXSER1: U1.D19, U5.B11
/fpga_bank/RXSER2: U1.A18, U5.B14
/fpga_bank/RXSER3: U1.B16, U5.B16
/fpga_bank/RXSER4: U1.B5, U5.P15
/fpga_bank/RXSER5: U1.E2, U5.P11
/fpga_bank/RXSER6: U1.E1, U5.T10
/fpga_bank/RXSER7: U1.L4, U5.P8
/fpga_bank/RXSERCLK0: U1.G19, U5.B8
/fpga_bank/RXSERCLK1: U1.E20, U5.A10
/fpga_bank/RXSERCLK2: U1.D18, U5.C13
/fpga_bank/RXSERCLK3: U1.A15, U5.D15
/fpga_bank/RXSERCLK4: U1.E7, U5.P14
/fpga_bank/RXSERCLK5: U1.C1, U5.T12
/fpga_bank/RXSERCLK6: U1.C3, U5.M10
/fpga_bank/RXSERCLK7: U1.J1, U5.R6
/fpga_bank/RXSYNC0: U1.F19, U5.B9
/fpga_bank/RXSYNC1: U1.D20, U5.A11
/fpga_bank/RXSYNC2: U1.B19, U5.A13
/fpga_bank/RXSYNC3: U1.B15, U5.C16
/fpga_bank/RXSYNC4: U1.C7, U5.N13
/fpga_bank/RXSYNC5: U1.E3, U5.N11
/fpga_bank/RXSYNC6: U1.F1, U5.T9
/fpga_bank/RXSYNC7: U1.H2, U5.R7
/fpga_bank/RXTSEL: U1.J19, U5.A5
/fpga_bank/T1OSCCLK: R17.1, U1.P3
/fpga_bank/TXMSYNC0: U1.J20, U5.D9
/fpga_bank/TXMSYNC1: U1.C20, U5.A12
/fpga_bank/TXMSYNC2: U1.A16, U5.C15
/fpga_bank/TXMSYNC3: U1.C17, U5.E14
/fpga_bank/TXMSYNC4: U1.E6, U5.P13
/fpga_bank/TXMSYNC5: U1.D2, U5.R11
/fpga_bank/TXMSYNC6: U1.G2, U5.R8
/fpga_bank/TXMSYNC7: U1.N4, U5.N6
/fpga_bank/TXON: R13.2, U1.L2, U5.T4
/fpga_bank/TXSER0: U1.L18, U5.E10
/fpga_bank/TXSER1: U1.H18, U5.C12
/fpga_bank/TXSER2: U1.D16, U5.D14
/fpga_bank/TXSER3: U1.A13, U5.F15
/fpga_bank/TXSER4: U1.D3, U5.N12
/fpga_bank/TXSER5: U1.H3, U5.P10
/fpga_bank/TXSER6: U1.G1, U5.T8
/fpga_bank/TXSER7: U1.K1, U5.P5
/fpga_bank/TXSERCLK0: U1.K18, U5.D10
/fpga_bank/TXSERCLK1: U1.A19, U5.B13
/fpga_bank/TXSERCLK2: U1.A17, U5.B15
/fpga_bank/TXSERCLK3: U1.C13, U5.E16
/fpga_bank/TXSERCLK4: U1.A2, U5.T14
/fpga_bank/TXSERCLK5: U1.G3, U5.N10
/fpga_bank/TXSERCLK6: U1.H1, U5.T7
/fpga_bank/TXSERCLK7: U1.N3, U5.P6
/fpga_bank/TXSYNC0: U1.K19, U5.C9
/fpga_bank/TXSYNC1: U1.B20, U5.B12
/fpga_bank/TXSYNC2: U1.B18, U5.A14
/fpga_bank/TXSYNC3: U1.A14, U5.E15
/fpga_bank/TXSYNC4: U1.B1, U5.T13
/fpga_bank/TXSYNC5: U1.E4, U5.M11
/fpga_bank/TXSYNC6: U1.L3, U5.N8
/fpga_bank/TXSYNC7: U1.K2, U5.T6
/fpga_bank/ULPI_CLKOUT: U1.L19, U11.12
/fpga_bank/ULPI_DATA0: U1.T19, U11.16
/fpga_bank/ULPI_DATA1: U1.T20, U11.15
/fpga_bank/ULPI_DATA2: U1.R18, U11.14
/fpga_bank/ULPI_DATA3: U1.R20, U11.13
/fpga_bank/ULPI_DATA4: U1.P19, U11.11
/fpga_bank/ULPI_DATA5: U1.P20, U11.10
/fpga_bank/ULPI_DATA6: U1.N19, U11.9
/fpga_bank/ULPI_DATA7: U1.N20, U11.8
/fpga_bank/ULPI_DIR: U1.M19, U11.19
/fpga_bank/ULPI_DM: P2.A7, P2.B7, U11.5
/fpga_bank/ULPI_DP: P2.A6, P2.B6, U11.6
/fpga_bank/ULPI_NXT: U1.M20, U11.18
/fpga_bank/ULPI_REFCLK: R64.2, U11.23
/fpga_bank/ULPI_RESETB: R72.1, U1.U19, U11.22
/fpga_bank/ULPI_SHIELD: C128.2, P2.SH, R39.1
/fpga_bank/ULPI_STP: U1.U20, U11.20
/fpga_bank/VBUS_ULPI: C129.2, F2.2, P2.A4, P2.A9, P2.B4, P2.B9, R65.2
/fpga_bank/WR#: U1.E15, U5.F13
/fpga_cfg/ADBUS0: RN1.8, U10.16
/fpga_cfg/ADBUS1: RN1.7, U10.17
/fpga_cfg/ADBUS2: RN1.6, U10.18
/fpga_cfg/ADBUS3: RN1.5, U10.19
/fpga_cfg/CFG1: R38.2, U1.T4
/fpga_cfg/CSSPIN: R40.2, U1.R2, U14.1
/fpga_cfg/DONE: R31.2, R37.2, U1.Y3, U10.23
/fpga_cfg/FT_CS: U1.T1, U10.41
/fpga_cfg/FT_DM: P1.A7, P1.B7, U10.7
/fpga_cfg/FT_DP: P1.A6, P1.B6, U10.8
/fpga_cfg/FT_EECLK: R62.2, U9.2, U10.62
/fpga_cfg/FT_EECS: R1.2, U9.1, U10.63
/fpga_cfg/FT_EEDATA: R61.1, U9.3, U10.61
/fpga_cfg/FT_MISO: U1.U1, U10.40
/fpga_cfg/FT_MOSI: U1.V1, U10.39
/fpga_cfg/FT_OSCI: R63.2, U10.2
/fpga_cfg/FT_PWRSAV#: R68.2, R69.1, U10.59
/fpga_cfg/FT_RESET#: R67.2, U10.14
/fpga_cfg/FT_SHIELD: C126.2, P1.SH, R70.1
/fpga_cfg/FT_V1P8_LDO: C91.1, C99.2, C120.2, C122.2, U10.12, U10.37, U10.49, U10.64
/fpga_cfg/INITN: D2.C, R32.2, U1.V3
/fpga_cfg/IO2: R43.2, U1.Y2, U14.3
/fpga_cfg/IO3: R44.2, U1.W1, U14.7
/fpga_cfg/JTAG_ACT: D3.C, U10.21
/fpga_cfg/MCLK: R26.2, U14.6
/fpga_cfg/MISO: R42.2, U1.V2, U14.2
/fpga_cfg/MOSI: R41.2, U1.W2, U14.5
/fpga_cfg/TCK: J5.4, R50.1, RN1.1, U1.T5
/fpga_cfg/TDI: J5.8, R47.2, RN1.2, U1.R5
/fpga_cfg/TDO: J5.6, R46.2, RN1.3, U1.V4
/fpga_cfg/TMS: J5.2, R48.2, RN1.4, U1.U5
/fpga_cfg/VBUS_FT: F3.2, P1.A4, P1.A9, P1.B4, P1.B9, R68.1
/framer/RRING0: J1.37, U5.C1
/framer/RRING1: J1.31, U5.E1
/framer/RRING2: J1.27, U5.G1
/framer/RRING3: J1.21, U5.J1
/framer/RRING4: J1.17, U5.L1
/framer/RRING5: J1.11, U5.N1
/framer/RRING6: J1.7, U5.R1
/framer/RRING7: J1.1, U5.T3
/framer/RTIP0: J1.38, U5.B1
/framer/RTIP1: J1.32, U5.D1
/framer/RTIP2: J1.28, U5.F1
/framer/RTIP3: J1.22, U5.H1
/framer/RTIP4: J1.18, U5.K1
/framer/RTIP5: J1.12, U5.M1
/framer/RTIP6: J1.8, U5.P1
/framer/RTIP7: J1.2, U5.T2
/framer/TCK: J3.4, R22.2, U5.D8
/framer/TDI: J3.8, R15.1, U5.C8
/framer/TDO: J3.6, R14.1, U5.B6
/framer/TMS: J3.2, R20.1, U5.A6
/framer/TRING0: J1.39, U5.D3
/framer/TRING1: J1.33, U5.E4
/framer/TRING2: J1.29, U5.G4
/framer/TRING3: J1.23, U5.H4
/framer/TRING4: J1.19, U5.J4
/framer/TRING5: J1.13, U5.L4
/framer/TRING6: J1.9, U5.M4
/framer/TRING7: J1.3, U5.P4
/framer/TRST: J3.10, R21.1, U5.D7
/framer/TTIP0: J1.40, U5.C3
/framer/TTIP1: J1.34, U5.E3
/framer/TTIP2: J1.30, U5.G3
/framer/TTIP3: J1.24, U5.H3
/framer/TTIP4: J1.20, U5.J3
/framer/TTIP5: J1.14, U5.L3
/framer/TTIP6: J1.10, U5.M3
/framer/TTIP7: J1.4, U5.P3
/power/FPGA_V1P1: C1.1, C2.1, C3.1, C4.1, C5.1, C6.1, C7.1, C8.1, C10.1, C11.1, C13.1, C14.1, C25.2, C26.1, C80.1, L4.2, R45.1, U1.H8, U1.H9, U1.H10, U1.H11, U1.H12, U1.H13, U1.J8, U1.J13, U1.K8, U1.K13, U1.L8, U1.L13, U1.M8, U1.M13, U1.N8, U1.N9, U1.N10, U1.N11, U1.N12, U1.N13
/power/FPGA_V2P5: C86.1, L1.1, U7.5
/power/FRAMER_V1P8: C31.1, C32.1, C42.1, C43.1, C47.1, C48.1, C52.1, C53.1, C58.1, C59.1, C64.1, C65.1, C70.1, C71.1, C76.1, C77.1, C88.1, C131.2, L6.1, U5.F8, U5.F9, U5.F10, U5.G6, U5.H6, U5.H11, U5.J6, U5.J11, U5.K6, U5.K11, U5.L7, U5.L8, U5.L9, U5.L10, U8.1, U8.2, U8.3, U11.21
/power/FRAMER_V3P3: C28.1, C29.1, C34.1, C37.1, C40.1, C41.1, C45.1, C46.1, C50.1, C51.1, C55.1, C57.1, C61.1, C63.1, C67.1, C69.1, C73.1, C75.1, C79.1, C87.1, C89.1, C96.1, C97.1, C98.1, C100.1, C101.1, C102.1, C103.1, C104.1, C105.1, C107.1, C108.1, C109.1, C110.1, C111.1, C113.1, C114.1, C115.1, C116.1, C117.1, C118.1, C121.2, C123.2, C124.2, C125.2, C130.2, C132.2, J3.1, J5.1, L5.1, L7.1, L8.1, L9.1, L10.1, L11.1, R1.1, R14.2, R15.2, R18.2, R20.2, R21.2, R30.1, R31.1, R32.1, R33.1, R34.1, R35.1, R36.2, R38.1, R40.1, R41.1, R42.1, R43.1, R44.1, R46.1, R47.1, R48.1, R60.1, R62.1, R67.1, U1.F9, U1.F10, U1.F11, U1.F12, U1.H6, U1.H7, U1.H14, U1.H15, U1.J6, U1.J15, U1.L6, U1.L7, U1.L14, U1.L15, U1.M6, U1.M15, U1.P9, U1.P10, U5.A16, U5.D4, U5.E8, U5.E11, U5.F4, U5.F5, U5.G15, U5.H5, U5.K4, U5.K5, U5.M5, U5.M6, U5.M9, U5.N4, U5.N14, U5.T16, U6.1, U6.2, U6.3, U9.6, U9.8, U10.20, U10.31, U10.42, U10.50, U10.56, U11.3, U11.4, U11.17, U14.8
/power/V1P8_FRM_PLL: C56.1, C62.1, C68.1, C74.1, L6.2, U5.A3, U5.A4, U5.B3, U5.C5, U5.C6, U5.D5
/power/V3P3_FRM_RX: C33.1, C39.1, C44.1, C49.1, C54.1, C60.1, C66.1, C72.1, C78.1, L5.2, U5.B2, U5.D2, U5.F2, U5.H2, U5.K2, U5.M2, U5.P2, U5.T1
/power/VCCAUX: C9.1, C12.1, C15.1, C137.1, L1.2, U1.F6, U1.F15, U1.P6, U1.P15
/regulator/V1P1_EN: R6.1, U2.2
/regulator/V1P1_LL: C21.2, L4.1, R12.1, U2.6, U2.7, U2.8, U2.9, U2.10, U2.11
/regulator/V1P1_MODE: R23.1, U2.20
/regulator/V1P1_PGOOD: R3.1, U2.3
/regulator/V1P1_SW_IN: C16.2, C19.2, C136.2, R2.1, U2.12, U2.13, U2.14, U2.15, U2.16, U2.17, U2.19, U12.3
/regulator/V1P1_TRIP: R11.1, U2.21
/regulator/V1P1_VBST: C21.1, U2.4
/regulator/V1P1_VFB: C22.1, R29.2, R45.2, U2.1
/regulator/V1P1_VREG: C20.2, R3.2, R6.2, U2.18
/regulator/V1P8_LDO_IN: C83.1, R55.1, R58.1, U8.7, U8.8, U18.3
/regulator/V2P3_SW: L3.1, U4.6
/regulator/V2P3_SW_IN: C18.1, R5.1, R9.2, U4.7, U15.3
/regulator/V2P3_SW_OUT: C24.1, C38.1, L3.2, R27.2, R55.2, U18.1
/regulator/V2P5_LDO_IN: C82.2, R51.1, R57.2, U7.1, U17.3
/regulator/V3P3_LDO_IN: C81.2, R49.1, R56.1, U6.7, U6.8, U16.3
/regulator/V3P8_SW: L2.1, U3.6
/regulator/V3P8_SW_IN: C17.2, R4.1, R7.2, U3.7, U13.3
/regulator/V3P8_SW_OUT: C23.1, C27.1, L2.2, R24.2, R49.2, R51.2, U16.1, U17.1
/regulator/VRAW: CON1.1, F1.2
/regulator/VRAW_FUSED: F1.1, F2.1, F3.1, Q2.3, Q3.3
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

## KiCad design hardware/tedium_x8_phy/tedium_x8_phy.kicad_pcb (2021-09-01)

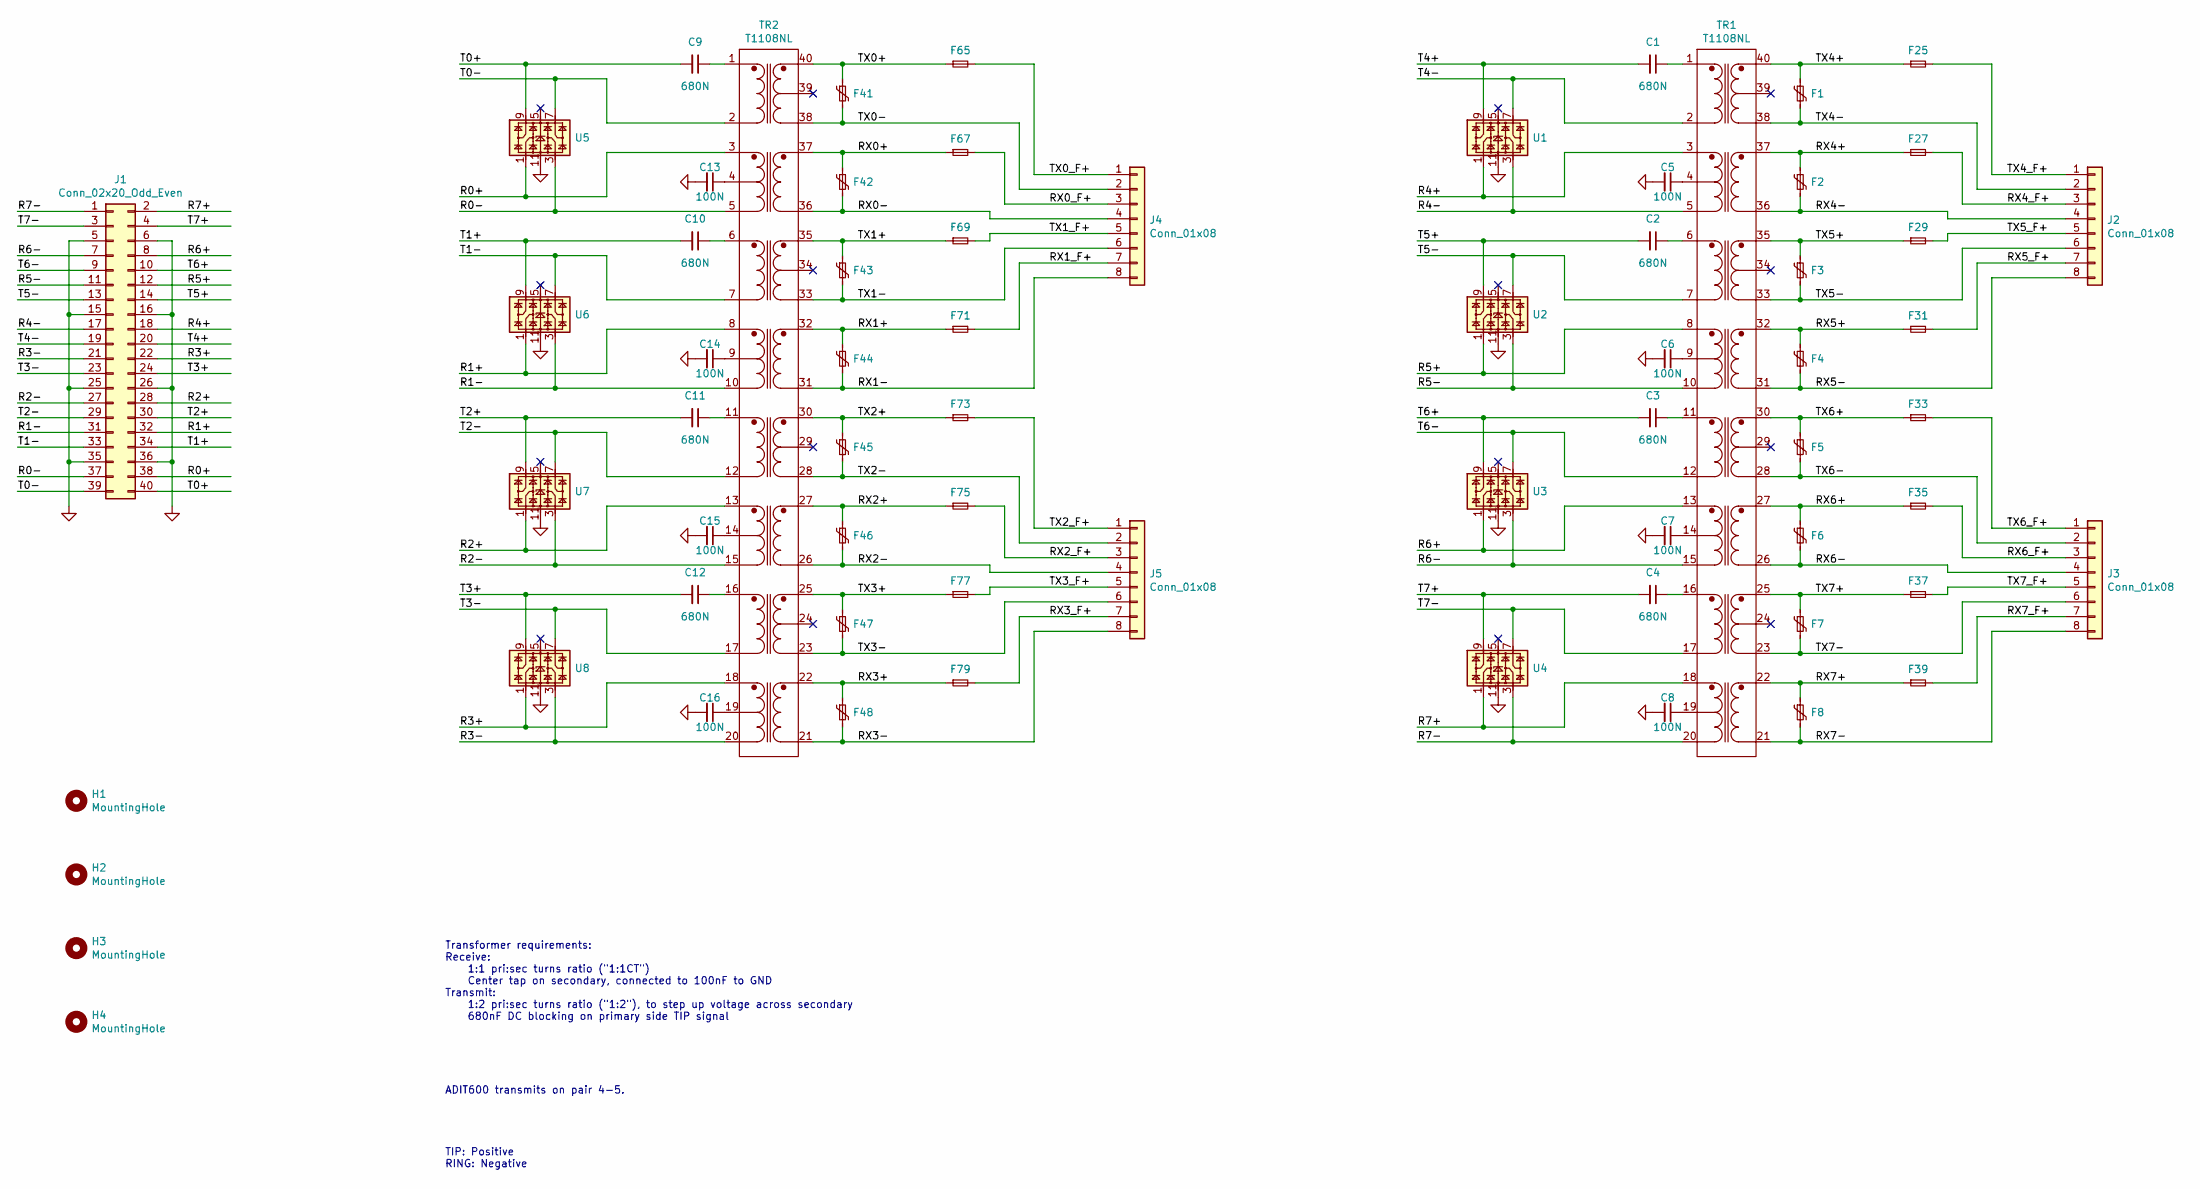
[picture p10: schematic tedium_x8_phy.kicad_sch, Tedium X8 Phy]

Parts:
C1, C2, C3, C4, C9, C10, C11, C12: 680N; IPC_CAPC200X125X135L45N; Part GCM21BR71E684KA55L
C5, C6, C7, C8, C13, C14, C15, C16: 100N; IPC_CAPC160X80X90L35N; Part GRM188R71C104KA01D
F1, F2, F3, F4, F5, F6, F7, F8, F41, F42, F43, F44, F45, F46, F47, F48: Polyfuse_Small; DO-214AA; Part ‎P0080SCMCLRP‎
F25, F27, F29, F31, F33, F35, F37, F39, F65, F67, F69, F71, F73, F75, F77, F79: Fuse_Small; 461; Part 04611.25ER
H1, H2, H3, H4: MountingHole; MountingHole_3.2mm_M3
J1: Conn_02x20_Odd_Even; PinHeader_2x20_P2.54mm_Vertical
J2, J3, J4, J5: Conn_01x08; SS-51000-003; Part SS-51000-003
TR1, TR2: T1108NL; TOU; Part T1108NL
U1, U2, U3, U4, U5, U6, U7, U8: RClamp3304NA; IPC_SON11P50_260X260X65L35X25T215X126N; Part RClamp3304NA

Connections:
/R0+: J1.38, TR2.3, U5.1
/R0-: J1.37, TR2.5, U5.3
/R1+: J1.32, TR2.8, U6.1
/R1-: J1.31, TR2.10, U6.3
/R2+: J1.28, TR2.13, U7.1
/R2-: J1.27, TR2.15, U7.3
/R3+: J1.22, TR2.18, U8.1
/R3-: J1.21, TR2.20, U8.3
/R4+: J1.18, TR1.3, U1.1
/R4-: J1.17, TR1.5, U1.3
/R5+: J1.12, TR1.8, U2.1
/R5-: J1.11, TR1.10, U2.3
/R6+: J1.8, TR1.13, U3.1
/R6-: J1.7, TR1.15, U3.3
/R7+: J1.2, TR1.18, U4.1
/R7-: J1.1, TR1.20, U4.3
/RX0+: F42.1, F67.1, TR2.37
/RX0-: F42.2, J4.4, TR2.36
/RX0_F+: F67.2, J4.3
/RX1+: F44.1, F71.1, TR2.32
/RX1-: F44.2, J4.8, TR2.31
/RX1_F+: F71.2, J4.7
/RX2+: F46.1, F75.1, TR2.27
/RX2-: F46.2, J5.4, TR2.26
/RX2_F+: F75.2, J5.3
/RX3+: F48.1, F79.1, TR2.22
/RX3-: F48.2, J5.8, TR2.21
/RX3_F+: F79.2, J5.7
/RX4+: F2.1, F27.1, TR1.37
/RX4-: F2.2, J2.4, TR1.36
/RX4_F+: F27.2, J2.3
/RX5+: F4.1, F31.1, TR1.32
/RX5-: F4.2, J2.8, TR1.31
/RX5_F+: F31.2, J2.7
/RX6+: F6.1, F35.1, TR1.27
/RX6-: F6.2, J3.4, TR1.26
/RX6_F+: F35.2, J3.3
/RX7+: F8.1, F39.1, TR1.22
/RX7-: F8.2, J3.8, TR1.21
/RX7_F+: F39.2, J3.7
/T0+: C9.2, J1.40, U5.9
/T0-: J1.39, TR2.2, U5.7
/T1+: C10.2, J1.34, U6.9
/T1-: J1.33, TR2.7, U6.7
/T2+: C11.2, J1.30, U7.9
/T2-: J1.29, TR2.12, U7.7
/T3+: C12.2, J1.24, U8.9
/T3-: J1.23, TR2.17, U8.7
/T4+: C1.2, J1.20, U1.9
/T4-: J1.19, TR1.2, U1.7
/T5+: C2.2, J1.14, U2.9
/T5-: J1.13, TR1.7, U2.7
/T6+: C3.2, J1.10, U3.9
/T6-: J1.9, TR1.12, U3.7
/T7+: C4.2, J1.4, U4.9
/T7-: J1.3, TR1.17, U4.7
/TX0+: F41.1, F65.1, TR2.40
/TX0-: F41.2, J4.2, TR2.38
/TX0_F+: F65.2, J4.1
/TX1+: F43.1, F69.1, TR2.35
/TX1-: F43.2, J4.6, TR2.33
/TX1_F+: F69.2, J4.5
/TX2+: F45.1, F73.1, TR2.30
/TX2-: F45.2, J5.2, TR2.28
/TX2_F+: F73.2, J5.1
/TX3+: F47.1, F77.1, TR2.25
/TX3-: F47.2, J5.6, TR2.23
/TX3_F+: F77.2, J5.5
/TX4+: F1.1, F25.1, TR1.40
/TX4-: F1.2, J2.2, TR1.38
/TX4_F+: F25.2, J2.1
/TX5+: F3.1, F29.1, TR1.35
/TX5-: F3.2, J2.6, TR1.33
/TX5_F+: F29.2, J2.5
/TX6+: F5.1, F33.1, TR1.30
/TX6-: F5.2, J3.2, TR1.28
/TX6_F+: F33.2, J3.1
/TX7+: F7.1, F37.1, TR1.25
/TX7-: F7.2, J3.6, TR1.23
/TX7_F+: F37.2, J3.5
GND: C5.2, C6.2, C7.2, C8.2, C13.2, C14.2, C15.2, C16.2, J1.5, J1.6, J1.15, J1.16, J1.25, J1.26, J1.35, J1.36, U1.11, U2.11, U3.11, U4.11, U5.11, U6.11, U7.11, U8.11
unnamed: C1.1, TR1.1
unnamed: C2.1, TR1.6
unnamed: C3.1, TR1.11
unnamed: C4.1, TR1.16
unnamed: C5.1, TR1.4
unnamed: C6.1, TR1.9
unnamed: C7.1, TR1.14
unnamed: C8.1, TR1.19
unnamed: C9.1, TR2.1
unnamed: C10.1, TR2.6
unnamed: C11.1, TR2.11
unnamed: C12.1, TR2.16
unnamed: C13.1, TR2.4
unnamed: C14.1, TR2.9
unnamed: C15.1, TR2.14
unnamed: C16.1, TR2.19

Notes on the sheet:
Transformer requirements: Receive: 1:1 pri:sec turns ratio ("1:1CT") Center tap on secondary, connected to 100nF to GND Transmit: 1:2 pri:sec turns ratio ("1:2"), to step up voltage across secondary 680nF DC blocking on primary side TIP signal
ADIT600 transmits on pair 4-5.
TIP: Positive RING: Negative

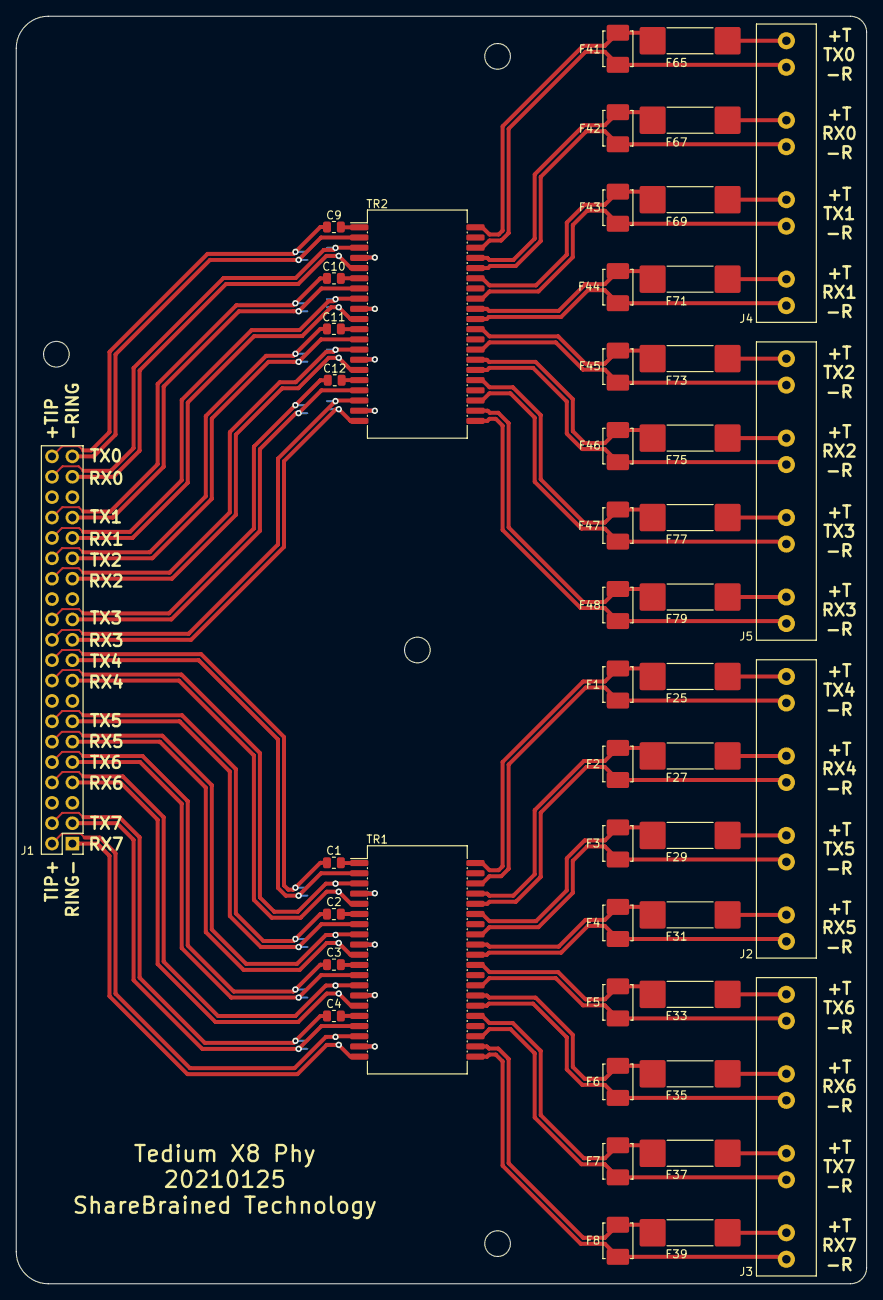
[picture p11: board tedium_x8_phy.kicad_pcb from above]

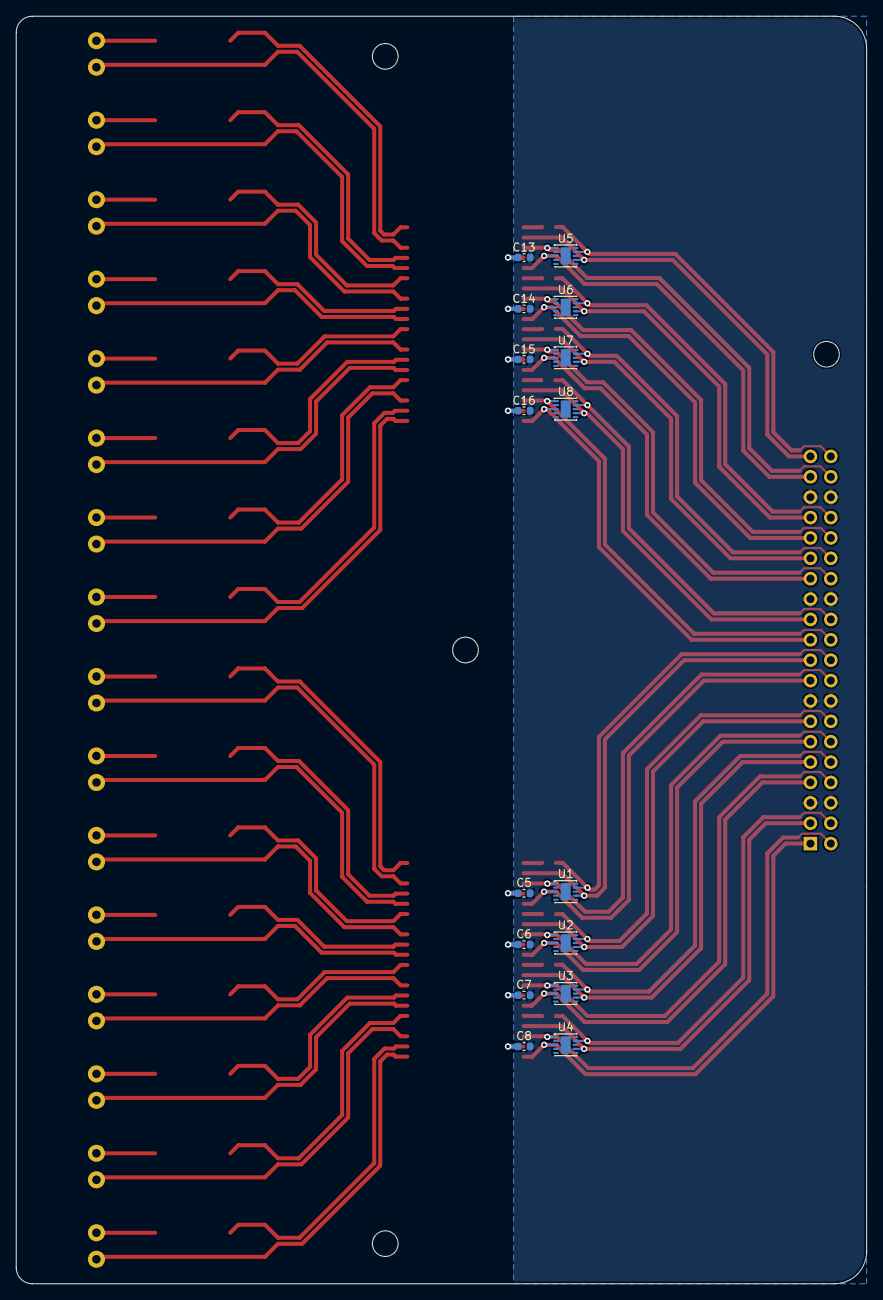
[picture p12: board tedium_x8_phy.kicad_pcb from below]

Board: 2 copper layers, 106.0 x 158.0 mm, 67 parts (16 on the bottom side), 97 nets.

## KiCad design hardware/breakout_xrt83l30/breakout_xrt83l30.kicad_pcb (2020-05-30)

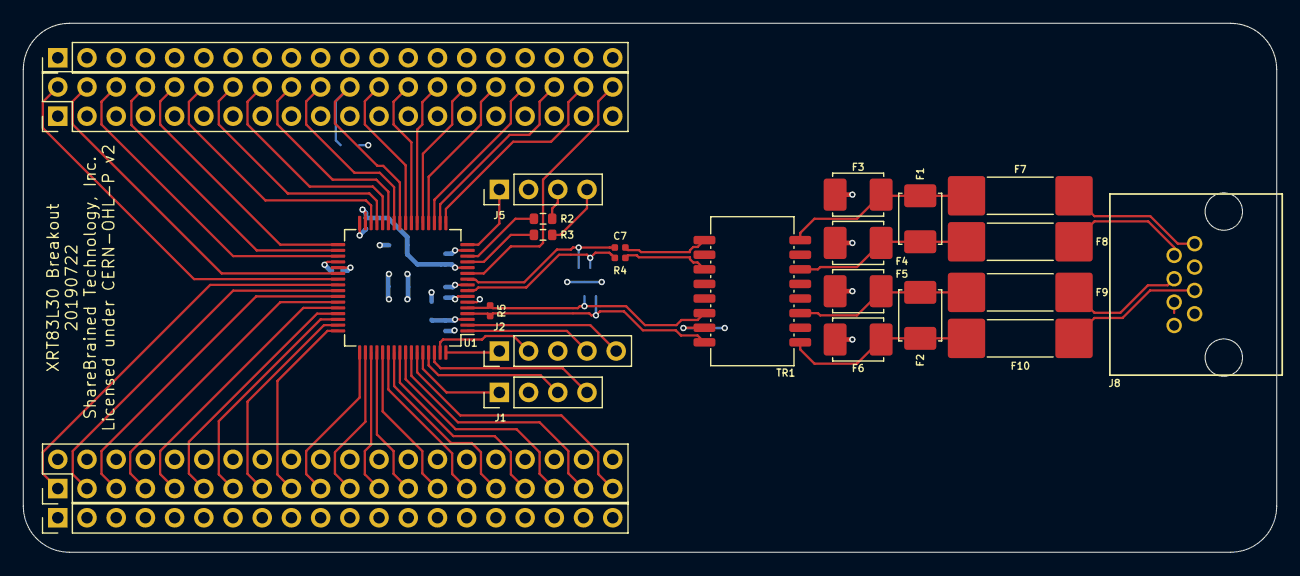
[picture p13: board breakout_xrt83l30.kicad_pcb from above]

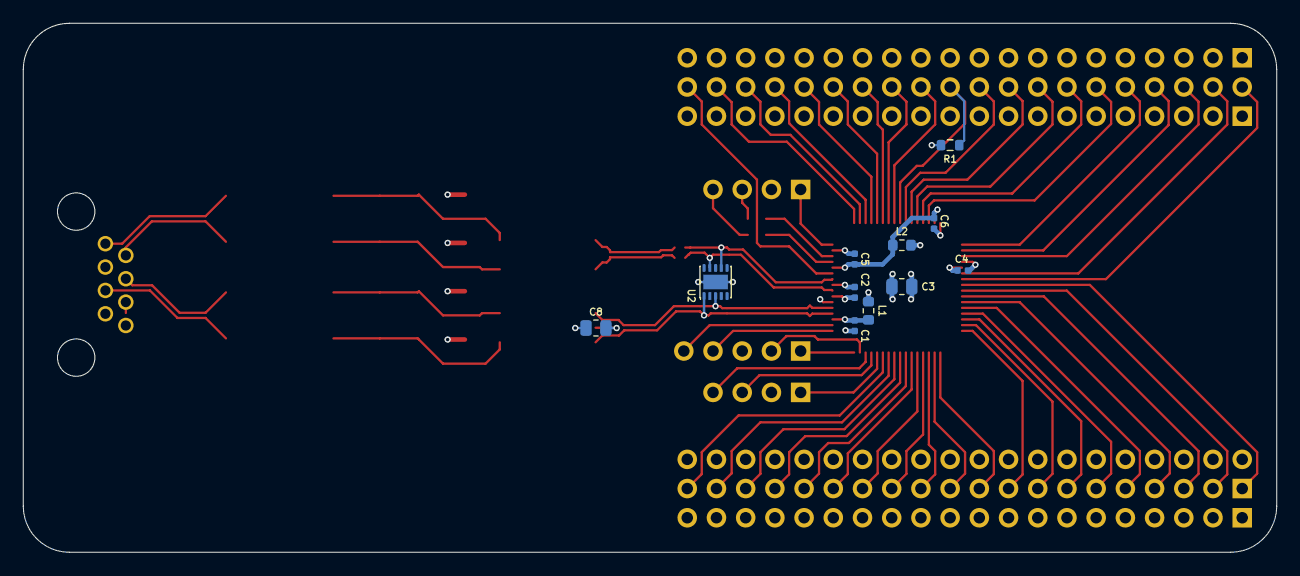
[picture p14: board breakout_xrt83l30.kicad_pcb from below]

Board: 4 copper layers, 109.0 x 46.0 mm, 36 parts (11 on the bottom side), 71 nets.

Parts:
C1, C2, C4, C5, C6: 100N; IPC_CAPC100X50X55L25N
C3: 10U; IPC_CAPC200X125X135L45N
C7: 680N; IPC_CAPC100X50X55L25N
C8: ?; IPC_CAPC200X125X135L45N
F1, F2, F3, F4, F5, F6: Polyfuse; DO-214AA
F7, F8, F9, F10: Fuse; 461
J1, J5: Conn_01x04; PinHeader_1x04_P2.54mm_Vertical
J2: Conn_01x05; PinHeader_1x05_P2.54mm_Vertical
J3, J7: Conn_01x20; PinHeader_1x20_P2.54mm_Vertical
J4, J6: Conn_02x20_Odd_Even; PinHeader_2x20_P2.54mm_Vertical
J8: RJ45; AMPHENOL_RJHSE5080
L1, L2: L; IPC_INDC160X80X100L30N
R1: 10K; IPC_RESC160X80X55L25N
R2, R3: 100R; IPC_RESC160X80X55L25N
R4: 0R; IPC_RESC100X50X40L25N
R5: DNP; IPC_RESC100X50X40L25N
TR1: BH_1; BH
U1: XRT83L30; IPC_QFP64P50_1200X1200X160L60X20N
U2: RClamp3304NA; IPC_SON11P50_260X260X65L35X25T215X126N

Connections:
/AISD: J6.2, U1.39
/ATAOS: J6.18, U1.27
/AVDD: C5.2, C6.2, L2.1, U1.12, U1.31
/CLKSEL0: J6.34, U1.19
/CLKSEL1: J6.36, U1.18
/CLKSEL2: J6.38, U1.17
/DMO: J6.40, U1.11
/EQC0_~INT: J6.22, R1.2, U1.25
/EQC1_~CS: J6.24, U1.24
/EQC2_SCLK: J6.26, U1.23
/EQC3_SDO: J6.28, U1.22
/EQC4_SDI: J6.30, U1.21
/GAUGE: J4.19, U1.49
/HW_~HOST: J6.32, U1.20
/INSBPV: J6.6, U1.35
/JABW: J4.13, U1.46
/JASEL0: J4.17, U1.48
/JASEL1: J4.15, U1.47
/LIU_RX_N: R5.2, TR1.14, U1.5, U2.3
/LIU_RX_P: R5.1, TR1.16, U1.4, U2.1
/LIU_TX_1_N: C7.1, TR1.9
/LIU_TX_1_P: R4.1, TR1.11
/LIU_TX_N: C7.2, U1.10, U2.7
/LIU_TX_P: R4.2, U1.8, U2.9
/LOOP0: J6.12, U1.30
/LOOP1: J6.14, U1.29
/MCLKE1: J5.4, R3.1
/MCLKOUT: J5.1, U1.16
/MCLKT1: J5.3, R2.1
/NLCD: J6.4, U1.38
/NLCDE0: J6.8, U1.34
/NLCDE1: J6.10, U1.33
/QRPD: J4.1, U1.40
/RAVDD: C1.2, L1.1, U1.3
/RCLK: J2.1, U1.64
/RCLKE: J4.27, U1.53
/RLOS: J2.2, U1.63
/RNEG_LCV: J2.4, U1.1
/RPOS_RDATA: J2.5, U1.2
/RXMUTE: J4.21, U1.50
/RXRES0: J4.25, U1.52
/RXRES1: J4.23, U1.51
/RXTSEL: J4.9, U1.44
/RX_1_N: F2.1, F5.1, F9.2, TR1.3
/RX_1_P: F2.2, F6.2, F10.2, TR1.1
/RX_N: F9.1, J8.4
/RX_P: F10.1, J8.5
/SD_~DR: J6.16, U1.28
/TCLK: J1.1, U1.60
/TCLKE: J4.35, U1.57
/TERSEL0: J4.5, U1.42
/TERSEL1: J4.7, U1.43
/TNEG_CODES: J1.4, U1.62
/TPOS_TDATA: J1.3, U1.61
/TRATIO: J6.20, U1.26
/TXON: J4.37, U1.58
/TXTEST0: J4.33, U1.56
/TXTEST1: J4.31, U1.55
/TXTEST2: J4.29, U1.54
/TXTSEL: J4.11, U1.45
/TX_1_N: F1.1, F3.1, F7.2, TR1.8
/TX_1_P: F1.2, F4.2, F8.2, TR1.6
/TX_N: F7.1, J8.1
/TX_P: F8.1, J8.2
/~ICT: J4.39, U1.59
/~RESET: J4.3, U1.41
GND: C1.1, C2.1, C3.2, C4.1, C5.1, C6.1, C8.2, F3.2, F4.1, F5.2, F6.1, J1.2, J2.3, J3.2, J3.3, J3.4, J3.5, J3.6, J3.7, J3.8, J3.9, J3.10, J3.11, J3.12, J3.13, J3.14, J3.15, J3.16, J3.17, J3.18, J3.19, J3.20, J5.2, J6.5, J6.7, J6.9, J6.11, J6.13, J6.15, J6.17, J6.19, J6.21, J6.23, J6.25, J6.27, J6.29, J6.31, J6.33, J6.35, J6.37, U1.6, U1.7, U1.15, U1.32, U1.37, U2.11
unnamed: C8.1, TR1.15
unnamed: R2.2, U1.14
unnamed: R3.2, U1.13
VDD: C2.2, C3.1, C4.2, J4.4, J4.6, J4.8, J4.10, J4.12, J4.14, J4.16, J4.18, J4.20, J4.22, J4.24, J4.26, J4.28, J4.30, J4.32, J4.34, J4.36, J4.38, J4.40, J7.3, J7.4, J7.5, J7.6, J7.7, J7.8, J7.9, J7.10, J7.11, J7.12, J7.13, J7.14, J7.15, J7.16, J7.17, J7.18, J7.19, L1.2, L2.2, R1.1, U1.9, U1.36

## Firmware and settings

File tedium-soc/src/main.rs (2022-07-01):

#![no_std]
#![no_main]

extern crate panic_halt;

use embedded_hal::prelude::*;
// use riscv::register;
use riscv_rt::entry;

use xrt86vx38_pac::{self, device::{Result, Xyz, Channel, Timeslot, DeviceAccess}};
use xrt86vx38_pac::register::*;

mod framer;
mod peripheral;
mod test_points;
mod uart;
mod usb;

use framer::{Device, Access, FramerControl};
use test_points::TestPoints;
use uart::Uart;
use usb::{USBEndpointIn, USBEndpointOut};

// TODO: Keep synchronized with `gateware/descriptors_vendor.py`.
// TODO: This is a duplicate of the data in the `tedium-tool` project.
#[derive(Copy, Clone, Debug)]
#[repr(u8)]
pub(crate) enum AlternateSetting {
    Idle = 0,
    Active = 1,
}

// TODO: Keep synchronized with `gateware/descriptors_vendor.py`.
// TODO: This is a duplicate of the data in the `tedium-tool` project.
#[derive(Copy, Clone, Debug)]
#[repr(u8)]
pub(crate) enum InterfaceNumber {
    FrameStream = 0,
    Interrupt = 1,
    FramerControl = 2,
}

// TODO: Keep synchronized with `gateware/descriptors_vendor.py`.
// TODO: This is a duplicate of the data in the `tedium-tool` project.
#[derive(Copy, Clone, Debug)]
#[repr(u8)]
pub(crate) enum EndpointNumber {
    FrameStream = 1,
    Interrupt = 2,
    FramerControl = 3,
}

// TODO: Keep synchronized with `gateware/descriptors_vendor.py`.
// TODO: This is a duplicate of the data in the `tedium-tool` project.
const FRAMER_CONTROL_BYTES_MAX: usize = 512;

fn configure_channel<D: Xyz>(channel: &Channel<D>) -> Result<()> {
    // THEORY?
    // NOTE: I *think* the clock loss detection feature is not effective
    // in our case, as channels are currently configured to use TxSERCLK_n
    // as their transmit clock source ("External Timing Modee"). The FPGA
    // is "wired" to take the recovered clock from one of the channels and
    // mirror it to the TxSERCLK on all channels.

    channel.csr().write(|w| w
        .with_LCV_Insert(0)
        .with_Set_T1_Mode(1)
        .with_Sync_All_Transmitters_to_8kHz(0)
        .with_Clock_Loss_Detect(1)
        .with_CSS(ClockSource::External)
    )?;

    channel.licr().write(|w| w
        .with_FORCE_LOS(0)
        .with_Single_Rail_Mode(0)
        .with_LB(FramerLoopback::No)
        .with_Encode_B8ZS(0)
        .with_Decode_AMI_B8ZS(0)
    )?;

    channel.fsr().write(|w| w
        // Update RX RSAR and transmitted RBS only on superframe boundaries.
        .with_Signaling_update_on_Superframe_Boundaries(1)
        .with_Force_CRC_Errors(0)
        .with_J1_MODE(0)
        .with_ONEONLY(1)    // Not the default, maybe more reliable sync?
        .with_FASTSYNC(0)
        .with_FSI(T1Framing::ExtendedSuperFrame)
    )?;

    channel.smr().write(|w| w
        .with_MFRAMEALIGN(0)    // Not used in base rate mode
        .with_MSYNC(0)    // Not used in base rate mode
        .with_Transmit_Frame_Sync_Select(0)
        .with_CRC6_Bits_Source_Select(0)
        .with_Framing_Bits_Source_Select(0)
    )?;

    channel.fcr().write(|w| w
        .with_Reframe(0)
        .with_Framing_with_CRC_Checking(1)
        .with_LOF_Tolerance(2)
        .with_LOF_Range(5)
    )?;

    // HDLC1 (for Facilities Data Link, right?)
    // Use "MOS" mode if we want 0b01111110 idle code with HDLC messages
    // (including reporting). Setting this makes the Adit 600s very happy,
    // stops the Adit from getting stuck when bringing up a channel.
    // Still gets stuck in payload loopback mode. Maybe it's important to
    // have MOS set *before* the channel starts sending frames, so that the
    // Adit doesn't autodetect(?) a BOS DLC channel instead of a MOS one?
    // So I've moved this to configure_channel().
    channel.dlcr1().modify(|m| m
        .with_SLC96_Data_Link_Enable(0)
        .with_MOS_ABORT_Disable(0)
        .with_Rx_FCS_DIS(0)
        .with_AutoRx(0)
        .with_Tx_ABORT(0)
        .with_Tx_IDLE(0)
        .with_Tx_FCS_EN(0)
        .with_MOS_BOSn(1)       
    )?;

    if true {
        // Performance reports
        channel.tsprmcr().modify(|m| m
            .with_FC_Bit(0)
            .with_PA_Bit(0)
            .with_U1_Bit(0)
            .with_U2_Bit(0)
            .with_R_Bit(0b0000)
        )?;
        channel.prcr().modify(|m| m
            .with_LBO_ADJ_ENB(0)
            .with_FAR_END(0)
            .with_NPRM(0b00)
            .with_C_R_Bit(0)
            .with_APCR(AutomaticPerformanceReport::EverySecond)
        )?;
    }

    channel.sbcr().write(|w| w
        .with_TxSB_ISFIFO(0)
        .with_SB_FORCESF(0)
        .with_SB_SFENB(0)
        .with_SB_SDIR(1)
        .with_SB_ENB(ReceiveSlipBuffer::SlipBuffer)
    )?;

    channel.ticr().write(|w| w
        .with_TxSyncFrD(0)
        .with_TxPLClkEnb_TxSync_Is_Low(0)
        .with_TxFr1544(0)
        .with_TxICLKINV(0)
        .with_TxIMODE(0b00)
    )?;

    channel.ricr().write(|w| w
        .with_RxSyncFrD(0)
        .with_RxPLClkEnb_RxSync_Is_Low(0)
        .with_RxFr1544(1)
        .with_RxICLKINV(0)
        .with_RxMUXEN(0)
        .with_RxIMODE(0b00)
    )?;

    channel.liuccr0().write(|w| w
        .with_QRSS_n_PRBS_n(PRBSPattern::PRBS)
        .with_PRBS_Rx_n_PRBS_Tx_n(PRBSDestination::TTIP_TRING)
        .with_RXON_n(1)
        .with_EQC(0x08)
    )?;

    channel.liuccr1().write(|w| w
        .with_RXTSEL_n(Termination::Internal)
        .with_TXTSEL_n(Termination::Internal)
        .with_TERSEL(TerminationImpedance::Ohms100)
        .with_RxJASEL_n(1)
        .with_TxJASEL_n(1)
        .with_JABW_n(0)
        .with_FIFOS_n(0)
    )?;

    channel.liuccr2().write(|w| w
        .with_INVQRSS_n(0)
        .with_TXTEST(TransmitTestPattern::None)
        .with_TXON_n(1)
        .with_LOOP2_n(LIULoopback::None)
    )?;

    for timeslot in channel.timeslots() {
        configure_timeslot(&timeslot)?;
    }

    Ok(())
}

fn configure_timeslot<D: Xyz>(timeslot: &Timeslot<D>) -> Result<()> {
    timeslot.tccr().write(|w| w
        .with_LAPDcntl(TransmitLAPDSource::TSDLSR_TxDE)
        .with_TxZERO(ZeroCodeSuppression::None)
        .with_TxCOND(ChannelConditioning::Unchanged)
    )?;

    // Python code was using TUCR = 0, but seems like the chip default is fine or better.
    timeslot.tucr().write(|w| w
        .with_TUCR(0b0001_0111)
    )?;

    // Enable Robbed-Bit Signaling (RBS), using the flag contents in this register,
    // instead of the values coming in via the PCM serial interface.
    timeslot.tscr().write(|w| w
        .with_A_x(0)
        .with_B_y(1)
        .with_C_x(0)
        .with_D_x(1)
        .with_Rob_Enb(1)
        .with_TxSIGSRC(ChannelSignalingSource::TSCR)
    )?;

    timeslot.rccr().write(|w| w
        .with_LAPDcntl(ReceiveLAPDSource::RSDLSR_RxDE)
        .with_RxZERO(ZeroCodeSuppression::None)
        .with_RxCOND(ChannelConditioning::Unchanged)
    )?;

    timeslot.rucr().write(|w| w
        .with_RxUSER(0b1111_1111)
    )?;

    timeslot.rscr().write(|w| w
        .with_SIGC_ENB(0)
        .with_OH_ENB(0)
        // Enable RBS debounce on this timeslot
        .with_DEB_ENB(1)
        .with_RxSIGC(ReceiveSignalingConditioning::SixteenCode_ABCD)
        .with_RxSIGE(ReceiveSignalingExtraction::SixteenCode_ABCD)
    )?;

    timeslot.rssr().write(|w| w
        .with_SIG_16A_4A_2A(0)
        .with_SIG_16B_4B_2A(0)
        .with_SIG_16C_4A_2A(0)
        .with_SIG_16D_4B_2A(0)
    )?;

    Ok(())
}

fn configure(device: &Device) -> Result<()> {
    device.liugcr4().write(|w| w
        .with_CLKSEL(ClockSelect::M16_384)
    )?;

    for channel in device.channels() {
        configure_channel(&channel)?;
    }

    Ok(())
}

fn enable_interrupts<D: Xyz>(channel: &Channel<D>) -> Result<()> {
    // Disable interrupts on all channels. Later, we'll enable
    // interrupts on the channel we want to watch and manage.
    channel.bier().write(|w| w
        .with_LBCODE_ENB(0)
        .with_RXCLKLOSS(0)
        .with_ONESEC_ENB(0)
        .with_HDLC_ENB(0)
        .with_SLIP_ENB(0)
        .with_ALARM_ENB(0)
        .with_T1FRAME_ENB(0)
    )?;

    // TODO: This is only here to test clock loss detection
    // channel.csr().modify(|m| m
    //     .with_Clock_Loss_Detect(0)
    // )?;

    // Enable interrupts and status

    // Enable receiver AIS detection
    channel.agr().modify(|m| m
        .with_Transmit_AIS_Pattern_Select(TransmitAISPattern::Disable)
        .with_AIS_Defect_Declaration_Criteria(AISDetection::UnframedAndFramed)
    )?;

    // Configure yellow alarm transmission
    // * One second rule
    channel.agr().modify(|m| m
        .with_Yellow_Alarm_One_Second_Rule(1)
        .with_ALARM_ENB(0)
        .with_YEL(0b01)
    )?;

    // Enable Customer Installation alarm detect (only in ESF)
    channel.ciagr().modify(|m| m
        // .with_CIAD(0b01)    // Enable unframed AIS-CI alarm detection
        .with_CIAD(0b10)    // Enable the RAI-CI alarm detection
    )?;

    // Enable interrupt status automatic reset-upon-read behavior
    // Enable interrupts from framer block.
    channel.icr().modify(|m| m
        .with_INT_WC_RUR(0)
        .with_ENBCLR(0)     // NOTE: This clears interrupt *ENABLES*, not *STATUSES*. Whoops.
        .with_INTRUP_ENB(1)
    )?;

    if false {
        // T1 Synchronization Status Message (SSM)
        // channel.boccr().modify(|m| m
        // )?;
    }

    // In-band loopback (not applicable for ESF, right?)
    // channel.lccr0().modify(|m| m
    //     .with_RXLBCALEN(0b11)
    //     .with_RXLBCDLEN(0b11)
    //     .with_TXLBCLEN(0b11)
    //     .with_FRAMED(1)
    //     .with_AUTOENB(1)
    // )?;
    // channel.rxlbac().modify(|m| m
    //     .with_RXLBAC(0b000_1110)
    //     .with_RXLBACEN(1)
    // )?;
    // channel.rxldcr().modify(|m| m
    //     .with_RXLBDC(0b011_1000)
    //     .with_RXLBDCEN(1)
    // )?;

    // channel.rifr().modify(|m| m
    //     .with_FRAlarmMask(1)    // "mask" terminology is very confusing!
    // )?;

    // channel.prcr().modify(|m| m
    //     .with_RLOS_OUT_ENB(1)
    // )?;

    // Enable all interrupts, even though it *seems* the status registers
    // reflect events even if interrupts aren't enabled?
    channel.bier().modify(|m| m
        .with_LBCODE_ENB(0)
        .with_RXCLKLOSS(0)
        .with_ONESEC_ENB(0)
        .with_HDLC_ENB(1)
        .with_SLIP_ENB(1)
        .with_ALARM_ENB(1)
        .with_T1FRAME_ENB(1)
    )?;

    // Alarm & Error Interrupts
    channel.aeier().modify(|m| m
        .with_LCV_ENB(1)
        .with_RxOOF_ENB(1)
        .with_RxAIS_ENB(1)
        .with_RxYEL_ENB(1)
    )?;

    // Framer Interrupts
    channel.fier().modify(|m| m
        .with_DS0_ENB(1)    // I think this is only possible with non-ESF framing?
        .with_SIG_ENB(1)
        .with_COFA_ENB(1)
        .with_OOF_ENB(1)
        .with_FMD_ENB(1)    // Frame mimic seems to happen with some frequency?
        .with_SE_ENB(1)     // CRC-6 synchronization doesn't seem directly actionable.
        .with_FE_ENB(1)     // Framing bit errors don't necessarily indicate that synchronization has been lost.
    )?;

    // Data Link (HDLC1) Interrupts
    channel.dlier1().modify(|m| m
        .with_TxSOT_ENB(0)      // For what it's worth, automatic reporting produces this interrupt.
        .with_RxSOT_ENB(0)
        .with_TxEOT_ENB(0)      // For what it's worth, automatic reporting produces this interrupt.
        .with_RxEOT_ENB(1)
        .with_FCS_ERR_ENB(0)    // Seems like status we should check on RxEOT, but doesn't require interrupting
        .with_RxIDLE_ENB(0)     // Not sure this has any value.
    )?;

    // Slip Buffer Interrupts
    // We'll keep a close eye on these for now, assuming my audio pump isn't very refined or well-behaved yet.
    channel.sbier().modify(|m| m
        .with_TxFULL_ENB(1)
        .with_TxEMPT_ENB(1)
        .with_TxSLIP_ENB(1)
        .with_RxFULL_ENB(1)
        .with_RxEMPT_ENB(1)
        .with_RxSLIP_ENB(1)
    )?;

    // Enable change in Excessive Zero condition interrupt?
    channel.exzer().modify(|m| m
        .with_EXZ_ENB(1)
    )?;

    // Enable SS7 for LAPD Controller 1 interrupt?
    channel.ss7er1().modify(|m| m
        .with_SS7_ENB(0)
    )?;

    // Enable Change in Receive LOS Condition interrupt?
    channel.rlcier().modify(|m| m
        .with_RxLOS_ENB(0)  // NOTE: Datasheet has the sense of this bit inverted! 0 = Enabled? Huh?
    )?;

    // Enable Change in Receive AIS-CI / RAI-CI Condition interrupt?
    channel.ciaier().modify(|m| m
        .with_RxAIS_CI_ENB(0)
        .with_RxRAI_CI_ENB(0)
    )?;

    // Enable T1 BOC interrupts?
    channel.bocier().modify(|m| m
        .with_RMTCH3(0)
        .with_RMTCH2(0)
        .with_BOCC(0)
        .with_RFDLAD(0)
        .with_RFDLF(0)
        .with_TFDLE(0)
        .with_RMTCH1(0)
        .with_RBOC(0)
    )?;

    // Enable T1 Unstable BOC SSM interrupts?
    channel.bocuier().modify(|m| m
        .with_Unstable(0)
    )?;

    // Enable LIU channel interrupts?
    channel.liuccier().modify(|m| m
        .with_DMOIE_n(0)
        .with_FLSIE_n(0)
        .with_LCVIE_n(0)   // Only for framer bypass operation.
        .with_NLCDIE_n(0)
        .with_AISDIE_n(0)   // Only for framer bypass operation.
        .with_RLOSIE_n(0)
        .with_QRPDIE_n(0)
    )?;

    let clear_interrupts = true;
    if clear_interrupts {
        // Clear any pending HDLC buffers.
        // NOTE: Didn't help unstick HDLC messages I was expecting to receive from myself via analog loopback.
        channel.dlsr1().read()?;
        channel.dlsr2().read()?;
        channel.dlsr3().read()?;

        channel.rdlbcr1().read()?;
        channel.rdlbcr2().read()?;
        channel.rdlbcr3().read()?;

        for _ in 0..96 {
            channel.lapdbcr0(0).read()?;
            channel.lapdbcr1(0).read()?;
        }

        channel.ss7sr1().read()?;
        channel.ss7sr2().read()?;
        channel.ss7sr3().read()?;

        channel.sbisr().read()?;

        channel.aeisr().read()?;
        channel.exzsr().read()?;
        channel.ciasr().read()?;

        channel.fisr().read()?;
    }
    
    Ok(())
}

fn dump_registers<D: Xyz>(device: &D, uart: &Uart) {
    for s in 0..1 {
        for r in 0x100..0x200 {
            let address = (s << 12) + r;
            if address & 15 == 0 {
                uart.write_char(Uart::EOL);
                uart.write_hex_u16(address);
            }

            // let v = r & 0xff;
            let v = device.register_read(address as u16).unwrap();

            uart.write_char(Uart::SPACE);
            uart.write_hex_u8(v as u8);
        }

        uart.write_char(Uart::EOL);
    }
}

enum HostRequestError {
    WrongEndpoint,
    ShortPacket,
    LongPacket,
    InvalidCommand,
}

fn error_str(e: HostRequestError) -> &'static str {
    match e {
        HostRequestError::InvalidCommand => "invalid",
        HostRequestError::ShortPacket    => "short",
        HostRequestError::LongPacket     => "long",
        HostRequestError::WrongEndpoint  => "endpoint",
    }
}

type HostRequestResult<T> = core::result::Result<T, HostRequestError>;

#[derive(Copy, Clone, Debug)]
enum HostRequestCommand {
    RegisterRead(u16),
    RegisterWrite(u16, u8),
}

struct USBOutReader<'a> {
    ep: &'a USBEndpointOut,
}

impl<'a> USBOutReader<'a> {
    fn from_endpoint(ep: &'a USBEndpointOut) -> Self {
        Self {
            ep
        }
    }

    fn read(&self) -> HostRequestResult<u8> {
        if self.ep.get_have() != 0 {
            Ok(self.ep.get_data())
        } else {
            Err(HostRequestError::ShortPacket)
        }
    }
}

fn parse_host_request(usb_out: &USBEndpointOut) -> HostRequestResult<HostRequestCommand> {
    let reader = USBOutReader::from_endpoint(usb_out);

    let command = reader.read()?;
    match command {
        0x00 => {
            let l = reader.read()?;
            let h = reader.read()?;
            let address = ((h as u16) << 8) | (l as u16);
            Ok(HostRequestCommand::RegisterRead(address))
        },
        0x01 => {
            let l = reader.read()?;
            let h = reader.read()?;
            let address = ((h as u16) << 8) | (l as u16);
            let value = reader.read()?;
            Ok(HostRequestCommand::RegisterWrite(address, value))
        },

        _ => Err(HostRequestError::InvalidCommand),
    }
}
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

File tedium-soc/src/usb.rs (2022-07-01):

use crate::{peripheral::Peripheral, uart::Uart};

pub struct USBEndpointIn {
    p: Peripheral,
}

impl USBEndpointIn {
    pub fn new(p: u32) -> Self {
        Self {
            p: Peripheral::new(p),
        }
    }

    pub fn write_fifo(&self, v: u8) {
        self.p.register_write(0, v as u32);
    }

    pub fn transmit(&self, endpoint: u8) {
        self.p.register_write(1, endpoint as u32);
    }

    pub fn reset(&self) {
        self.p.register_write(2, 1);
    }

    pub fn set_stall(&self) {
        self.p.register_write(3, 1);
    }

    pub fn clear_stall(&self) {
        self.p.register_write(3, 0);
    }

    pub fn is_stalled(&self) -> bool {
        self.p.register_read(3) != 0
    }

    pub fn is_idle(&self) -> bool {
        self.p.register_read(4) != 0
    }

    pub fn is_fifo_empty(&self) -> bool {
        self.p.register_read(5) == 0
    }

    pub fn is_interrupt_pending(&self) -> bool {
        self.p.register_read(6) != 0
    }

    pub fn get_pid(&self) -> u8 {
        self.p.register_read(7) as u8
    }

    pub fn set_pid(&self, pid: u8) {
        self.p.register_write(7, pid as u32);
    }
}

pub struct USBEndpointOut {
    p: Peripheral,
}

impl USBEndpointOut {
    pub fn new(p: u32) -> Self {
        Self {
            p: Peripheral::new(p),
        }
    }

    pub fn get_data(&self) -> u8 {
        self.p.register_read(0) as u8
    }

    pub fn get_data_ep(&self) -> u8 {
        self.p.register_read(1) as u8
    }

    pub fn reset(&self) {
        self.p.register_write(2, 1);
    }

    pub fn get_epno(&self) -> u8 {
        self.p.register_read(3) as u8
    }

    pub fn set_epno(&self, v: u8) {
        self.p.register_write(3, v as u32);
    }

    pub fn get_enable(&self) -> u8 {
        self.p.register_read(4) as u8
    }

    pub fn set_enable(&self, v: u8) {
        self.p.register_write(4, v as u32);
    }

    pub fn set_prime(&self, v: u8) {
        self.p.register_write(5, v as u32);
    }

    pub fn get_stall(&self) -> u8 {
        self.p.register_read(6) as u8
    }

    pub fn set_stall(&self, v: u8) {
        self.p.register_write(6, v as u32);
    }

    pub fn get_have(&self) -> u8 {
        self.p.register_read(7) as u8
    }

    pub fn set_have(&self, v: u8) {
        self.p.register_write(7, v as u32);
    }

    pub fn get_pend(&self) -> u8 {
        self.p.register_read(8) as u8
    }

    pub fn set_pend(&self, v: u8) {
        self.p.register_write(8, v as u32);
    }

    pub fn get_pid(&self) -> u8 {
        self.p.register_read(9) as u8
    }

    pub fn set_pid(&self, v: u8) {
        self.p.register_write(9, v as u32);
    }

    pub fn get_ev_status(&self) -> u32 {
        self.p.register_read(11)
    }

    pub fn get_ev_pending(&self) -> u32 {
        self.p.register_read(12)
    }

    pub fn set_ev_pending(&self, v: u32) {
        self.p.register_write(12, v);
    }

    pub fn get_ev_enable(&self) -> u32 {
        self.p.register_read(13)
    }

    pub fn set_ev_enable(&self, v: u32) {
        self.p.register_write(13, v);
    }
}

///////////////////////////////////////////////////////////////////////
// Debugging stuff
// 

#[derive(Copy, Clone, Default, PartialEq)]
struct USBOutState {
    data_ep: u8,
    enable: u8,
    stall: u8,
    have: u8,
    pend: u8,
}

impl USBOutState {
    fn from_endpoint(ep: &USBEndpointOut) -> Self {
        USBOutState {
            data_ep: ep.get_data_ep(),
            enable: ep.get_enable(),
            stall: ep.get_stall(),
            have: ep.get_have(),
            pend: ep.get_pend(),
        }
    }

    fn print(&self, uart: &Uart) {
        uart.write_str("O[");
        uart.write_hex_u8(self.data_ep);
        uart.write_char(0x30 + self.enable);
        uart.write_char(0x30 + self.stall);
        uart.write_char(0x30 + self.have);
        uart.write_char(0x30 + self.pend);
        uart.write_str("]\n");
    }
}

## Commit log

2019-07-23 Hopefully complete XRT83L30 breakout design.
    [breakout_xrt83l30.kicad_pcb, breakout_xrt83l30.sch]
2020-05-29 Relocate XRT83L30 breakout schematic/PCB files.
    [breakout_xrt83l30.kicad_pcb, breakout_xrt83l30.sch]
2020-05-30 Update/apply XRT83L30 breakout schematic license and release dates.
    [breakout_xrt83l30.kicad_pcb, breakout_xrt83l30.sch]
2020-05-30 Add XRT83L30 breakout schematic for reference by non-KiCAD people.
2020-05-30 Update XRT83L30 breakout schematic -cache.lib because... why?
2020-05-30 Add Tedium X8 (8-span framer/LIU + FPGA + USB + power) schematic/PCB design.
    [fpga_bank.sch, fpga_cfg.sch, framer.sch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]
2020-05-30 Remove redundant cached library for XRT83L30 breakout board.
2021-09-01 HW: Tedium X8: Misc schematic comments.
    [fpga_bank.sch, fpga_cfg.sch]
2021-09-01 HW: Tedium X8: Add KiCAD 5.99 project file.
2021-09-01 Rework Rust framer to support ESF.
    [main.rs]
2021-09-01 Tedium X8 PHY initial design.
    Weak, but it does the job.
    [tedium_x8_phy.kicad_pcb, tedium_x8_phy.kicad_sch]
2021-09-01 HW: Tedium X8: Add .kicad_prl file
    I guess they separated out UI state from the rest of the project file? Maybe this doesn't belong in the repo?
2021-09-01 HW: Tedium X8: Remove old-KiCAD .pro file.
2021-09-01 Add my KiCAD repo as a submodule.
    I don't like this approach very much, but not sure what's better...
2021-09-01 HW: Tedium X8: Update symbols, footprints, KiCAD to 5.99-now.
    [fpga_bank.kicad_sch, fpga_bank.sch, fpga_cfg.kicad_sch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]
2021-09-02 Update license on old Rust framer code.
2021-09-19 Reorganize USB endpoint constants
    Borrowing structure from a USB audio device.
2021-09-19 Further USB descriptor tweaking.
    Set self-powered, 100mA current, remove serial number, add device version number.
2022-06-21 Remove old Rust framer code.
2022-06-21 Some Python ESF frame dumper I cobbled together...
2022-06-21 Whoops, enable TX side of FPGA framer.
2022-06-22 Remove message channel, track USB/frame sequences, move frames through ringbuf.
2022-06-22 Drain frame ringbuf as fast as possible.
2022-06-22 Naively pass received frame count to transmitted frame.
    Eventually, I intend for the FPGA to use the frame count as a presentation timestamp, and the host will advance the received count by a constant latency (number of frames). This should make latency m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
2022-06-22 Allow OUT handler to drain internal frame ringbuf completely.
2022-06-22 Rename internal frames ringbuf producer/consumer.
2022-06-22 First pass: collect and report framer statistics.
2022-06-22 Separate periodic and cumulative framer statistics.
2022-06-22 Quick cut at altering the audio/switch patching at runtime.
2022-06-22 Use thread::Builder to give threads names for better debugging.
2022-06-23 Reintroduce USB interrupt endpoint for framer INT#.
2022-06-23 Move USB config info into module, fix interrupt endpoint number.
    [usb.rs]
2022-06-24 Add USB interrupt IN endpoint simulation.
2022-06-24 Move framer->USB interrupt logic out of endpoint code.
2022-06-24 "Fix" framer->USB interrupts, at least temporariliy.
    TODO: This method certainly transmits far more interrupts than necessary, and likely wastes some small (likely insignificant) amount of the host's time. I suppose it offends me aesthetically more than anything.
2022-06-24 Missed committing sneaky comment about RTKit thread priority.
2022-06-25 Add common reset signal for PLLs, currently held at 0/false.
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2022-06-28 Add firmware Rust code and semi-generalized framer peripheral crate.
2022-06-28 Introduce SoC, move framer hardware reset control to SoC CSR.
2022-06-28 Add some useful bits to the dumb UART.
    Trying not to be embarrassed.
2022-06-28 firmware: basic interrupt checking.
2022-06-28 More-better IRQ checking.
    Still no actual interrupt signal stimuli, just lots of register polling.
2022-06-28 Add a couple of firmware start-up progress messages.
2022-06-29 More thorough clearing of HDLC/SS7-related interrupts.
2022-06-29 Firmware: Report interrupt status to host over USB IN endpoint.
2022-06-29 firmware: Accept USB OUT transfers.
    They're just being printed via the UART right now, but we'll do something more interesting with them soon...
2022-06-29 Remove a couple of bits of commented-out code.
2022-06-29 Generalize async USB transfer handler, improve framer interrupt thread..
2022-06-29 firmware: Only arm interrupt IN when there's data in the FIFO.
    This prevents a ton of zero-length packets (ZLPs) being sent to the host and waking it up unnecessarily.
    [main.rs]
2022-06-29 Pipe framer interrupt data through to receiver thread.
2022-06-29 firmware: Send correct RLCISRx registers for LBCODE, fix PAC crate.
    [main.rs]
2022-06-29 Parse and pretty-print framer interrupt messages.
    This needs to be refactored into separate parsing and presentation, obviously...
2022-06-30 Proper parsing and displaying of framer interrupts.
2022-06-30 Move framer register dump functions, remove commented code.
2022-06-30 Extract host requests into separate blob with its own Result/Error.
    [main.rs]
2022-06-30 Add some missing USB descriptor constants.
    [usb.rs]
2022-07-01 Firmware: Move USB IN interrupt checking to later to not starve host requests.
2022-07-01 Firmware: Tighten up RegisterRead, monitor for unexpected USB IN state.
    [main.rs]
2022-07-01 Firmware: Add UART test code.
    I might never use it again, but who knows...
2022-07-01 Test: Rename Python USB interrupt/host-command tests.
2022-07-01 Test: Fix the ringer host command test to use correct A/B bits for loop-start.
    [usb_host_command_test.py]
2022-07-01 Tool: Track received line state.
2022-07-10 Remove framer defaults from tedium-tool, will use xrt86vx38-pac soon.
2022-07-10 tedium-tool: Move framer interrupt handling to interrupt.rs.
2022-07-10 framer: Rework the interrupt handler a bit.
    Order of operations was less than ideal. We need to copy out of the libusb transfer buffer before we submit the transfer back to libusb.
    [main.rs]
2022-07-10 tedium-tool: Change placement of carriage returns in debug output.
2022-07-10 tedium-tool: Track line state and time-stamp hook-switch events.
    Pulse dialing is essential!
2022-07-10 tedium-tool: Move debug thread out of audio.rs, to main.rs:monitor.
2022-07-11 Add MF bits to RX frame, move signaling (DTMF/pulse) into separate thread.
    Don't burden the audio thread with DTMF processing, as a little latency will be totally acceptable. I'll eventually add hook-switch detection (pulse dialing, flash, on-hook events) based on RBS bits 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
2022-07-11 tedium-tool: print an error when the signaling ring buffer overflows.
2022-07-11 tedium-tool: Extract missing-frames detector.
2022-07-11 tedium-tool: Make audio debug messages easily switchable.
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

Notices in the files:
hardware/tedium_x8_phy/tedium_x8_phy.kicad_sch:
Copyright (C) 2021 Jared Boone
